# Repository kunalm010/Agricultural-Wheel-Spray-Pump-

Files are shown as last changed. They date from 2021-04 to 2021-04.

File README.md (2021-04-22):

# Agricultural-Wheel-Spray-Pump-
final assembly
Rear Shaft Sub Assembly
Front Shaft Sub Assembly
Crank_spray Frame sub Assembly
Frame Sub Assembly
Tank-Pump Sub Assembly

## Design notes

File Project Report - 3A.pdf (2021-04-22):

## Machine System Design

### A Project Report On

### “Agricultural Wheeled Spray Pump”

### Submitted by

### Group 3-A

### BT18MEC064 – KUNAL SONAWANE BT18MEC068 – SAURABH KHODE BT18MEC096 – BHAVIN YARDI

### Under the guidance of

### Prof. Dr. H.T.Thorat

### Department Of Mechanical Engineering

VNIT, Nagpur.

### 1. Name of Machine: Agricultural Wheeled Spray Pump

### 2. Purpose of the Machine: To spray pesticides on crops through

manual efforts.

This machine is a manually operated system and through this Machine we can reduce the maximum effort required for spraying Pesticides as well as we can spray pesticides in any direction or Around the crops at any height crops.

### 3. Design Objective: The conventional pesticide sprayers load the

farmer’s back with heavy storage tank which has to be carried all along the spraying process, which increases the efforts of the farmer. The objective of this machine is to fulfil the pesticide requirements of the farm at maximum rate, while reducing the efforts of the farmer.

### 4. Broad Design Specifications:

- Discharge – 3L/min
- No of nozzles – 3
- Area covered in one day – 6.4 Acre per day
- Spray per m2 – 82.873ml

### 5. Selection of Process and Mechanism:

Pressure Generation Process: Two types of pump can be used for the pressure generation process:

### 1. Centrifugal Pump: A centrifugal pump is a mechanical device

designed to move a fluid by means of the transfer of rotational energy from one or more driven rotors, called impellers.

The impeller is the key component of a centrifugal pump. It consists of a series of curved vanes. These are normally sandwiched between two discs (an enclosed impeller).

Fluid enters the impeller at its axis and exits along the circumference between the vanes. The impeller is connected through a drive shaft to a motor and rotated at high speed (typically 500-5000rpm). The rotational motion of the impeller accelerates the fluid out through the impeller vanes into the pump casing.

The action of the impeller increases the fluid’s velocity and pressure and also directs it towards the pump outlet.

There are two basic designs of pump casing: volute and diffuser. The purpose in both designs is to translate the fluid flow into a controlled discharge at pressure.

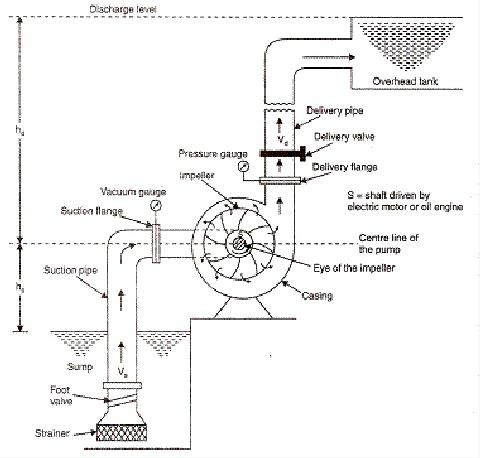
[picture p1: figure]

### 2. Reciprocating Pump: Reciprocating Pump is a Positive Displacement

type pump that works on the principle of movement of the piston in forwarding and backward directions.

It is a machine that converts mechanical energy into hydraulic energy. Reciprocating pumps are in use where a certain quantity of fluid has to be transported from the lowest region to the highest region by the application of pressure. The liquid is sucked keeping the delivery valve close and is pushed out while keeping the intake valve close creating a pressure at nozzle.

The rotatory motion of the wheel shall be used to drive the crank and convert the rotary motion into reciprocatory motion of the piston which will then cater to the process of pressure generation.

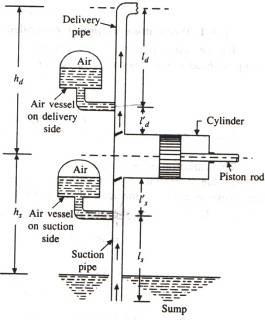
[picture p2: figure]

Pressure Generation is done by reciprocating pump.

- Advantages of reciprocating pump over centrifugal pump:
1. Reciprocating pump is used at a high-pressure head and Centrifugal Pumps are used at low or medium pressure head because the pressure generated in centrifugal pumps is limited due to the limitation on the speed of the shaft.
2. In reciprocating pumps low discharge is obtained which is a desired output for our case.

### 6. Design of Mechanism:

- Working of machine: The Reciprocating Pump has been used in the machine for pressure generation.

The slider crank Mechanism of the pump will be powered by the farmer himself. The total power requirement of the machine will depend on the discharge required as well as the height at which the pesticide is to be pumped. The discharge and the height of spray will vary from farm to farm and the calculations in this report have been done for the Wine-Yard farm. In addition, to the power required for spraying of pesticides the farmer will also need to exert some power to overcome the friction and facilitate the movement of the machine. Because there is a limit to the power which the farmer can exert, the discharge needs to be lowered by attaching the nozzles only one side of the frame. Chain Sprocket Mechanism has been used for power transmission. Freewheel has been attached on the crankshaft to avoid the power transmission in the reverse direction.

- Front Wheel Selection: A bigger wheel meant more stability to the cart but at the same time it would reduce the angular velocity of the front wheel, as the linear speed of the wheel would more or less remain constant. Lower angular velocity of the wheel would mean greater requirement of torque which would lead to the farmer exerting higher amount of force. Hence, we choose diameter of front wheel to be 30cm(smaller) and that of rear wheels to be 40cm(larger) thus ensuring stability and reducing overall torque requirement.
- Sprocket Wheel and Speed Ratio: In order to reduce the torque requirement, the angular velocity of the crankshaft needed to be increased. The lower limit on the size of the front wheel was fixed due to stability issues. Hence, the speed of the crankshaft had to be increased by choosing a suitable velocity ratio of the chain-sprocket mechanism. The velocity ratio had to be increase as much as possible. But the maximum velocity ratio attainable is 2:1.
- Freewheel: It is mounted on crankshaft connected with sprocket chain drive. It will be used in power transmission in forward direction. But for initial pressure built-up, instead of moving the cart and closing the nozzle’s opening, freewheel will be rotated

in reverse direction with the help of handle connected at the end of crankshaft, that will rotate the crankshaft and will setup initial pressure without moving the cart

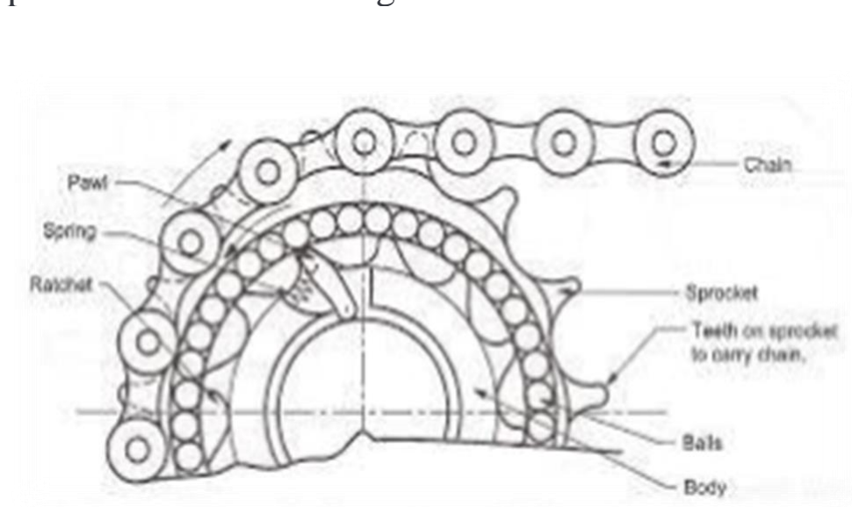
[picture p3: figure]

- DESIGN SELECTION: While using the reciprocating pump for the pressure generation process, the pump could be designed in two ways. One being with a fixed cylinder and the other with fixed piston. We analysed both the designs and finally decided to go with fixed cylinder reciprocating pump because of the following reasons:
1. Excessive length of linkages is required in the fixed piston type of reciprocating pump. Due to this, fixed piston type of reciprocating pump results in a less compact design.

2. As suction pipe will also reciprocate along with the cylinder in the fixed piston type of reciprocating pump, the design of suction pipe will create complication in design of actual pump.

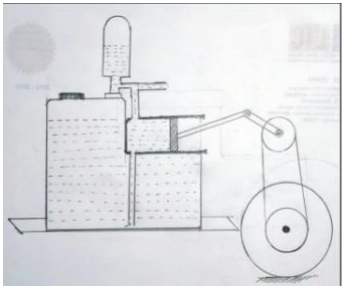
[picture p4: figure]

FIXED CYLINDER RECIPROCATING PUMP

FIXED PISTON RECIPROCATING PUMP

- Average Torque/Maximum Torque: The maximum angular velocity attainable on the machine is close to 90rpm which eliminates the use of flywheel in machine as flywheel works on higher rpm. Hence, the machine cannot be designed for average torque but has to be design for maximum torque required.

### 7. Power Transmission Chain:

### 8. Calculation of Power and Speed Requirement:

- Discharge = 3L/min
Assumed Cd = 0.5
Therefore, Design Discharge = 6L/min
- Number of Nozzles = 3
Therefore, Discharge per nozzle = 2L/min
- Speed of farmer = 0.7m/s
Radius of wheel = 0.15m
Angular speed of wheel = 4.67rad/s
Angular speed of crank = 9.34rad/s = 89.1267rpm Assumed Bore – stroke (d-l) ratio = 1:2

Calculation of bore diameter and stroke length,

FARMER | FRONT WHEEL
SPROCKET
PISTON | CRANK | FREEWHEEL

Since,

Bore diameter, d = 3.5cm
Stroke length, l = 7cm
- Calculation of Suction and Delivery pipe diameter,

Nozzle exit diameter = 2mm (Given Specification)

Therefore,

= 2L/min
Vexit = 10.6m/s (exit velocity at nozzle)

Nozzle inlet diameter = 6.35mm

Therefore,

= 2L/min

Vinlet = 1.05m/s (inlet velocity at nozzle)

Since, Velocity in suction pipe = velocity in delivery pipe = Vinlet = 1.05m/s

Therefore,

= 6L/min

Ds = 1.1cm

Therefore, diameter of suction pipe = diameter of delivery pipe = 1.1cm

- Calculation of suction and delivery head: Given Specifiaction:
Length of delivery pipe = 1m Length of suction pipe = 0.25m

Assuming the free surface of pesticides in tank as datum.

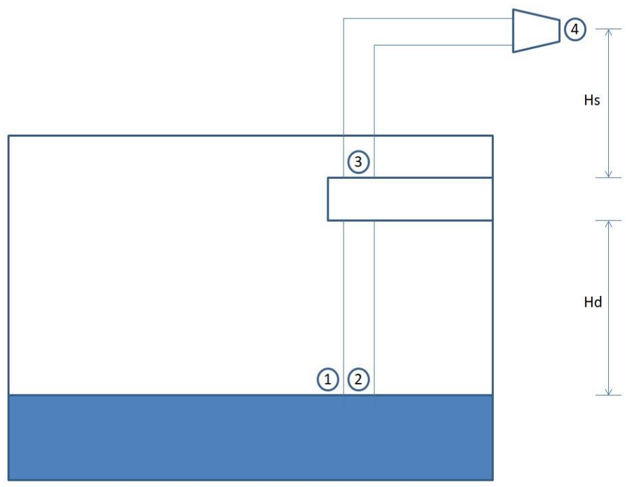
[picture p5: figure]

1. Suction head (Hs) =
+

Applying Bernoulli’s Principle on 1 and 2,

+ =

+

+

+ 0 =

+

+ h2

Therefore, Hs =
= 10.3m
2. Delivery head (Hd) =
+

Applying Bernoulli’s Principle on 3 and 4,

+ =

+

+

=

+ -

Therefore, Hd =
+ = 17.28
- Calculation of acceleration head Ha:

Ha =

Has =

= 0.008425cos ( )

Had =

= 0.337cos ( )

- Force required for generating head: During suction,

Fs =

( | )

=

( | ( | ))
Fs = 97.21 + 0.795cos ( | )

Fd =

( | )

= -

( | ( | ))

Fd = -(163.09 + 3.18cos ( ))

- Torque required for generating load:

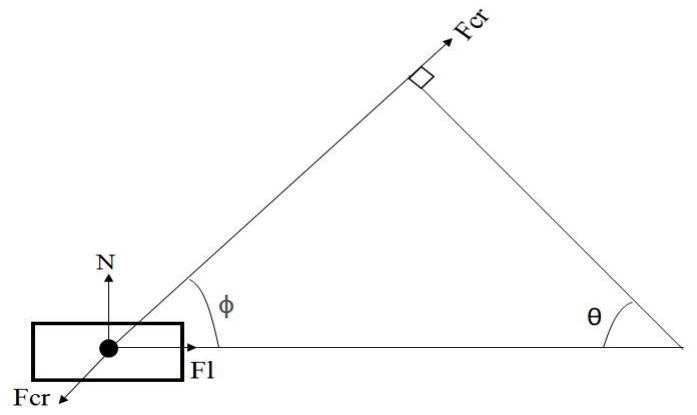
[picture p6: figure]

During suction,

Ts =

( | ) *
( | ) √ (
( | ))
+
√ (
| | | ( | ))
Ts = ( | ( | )) | ( | ) * | ( | ) √ ( | ( | ))
+
√ ( | ( | ))

During delivery,

Td =

( | ) *
( | ) √ (
( | ))
+
√ (
( ))

Td = -

( | ( | )) | ( | ) * | ( | ) √ ( | ( | ))
+
√ ( | ( | ))

- Plotting T VS diagram during delivery as well as suction.

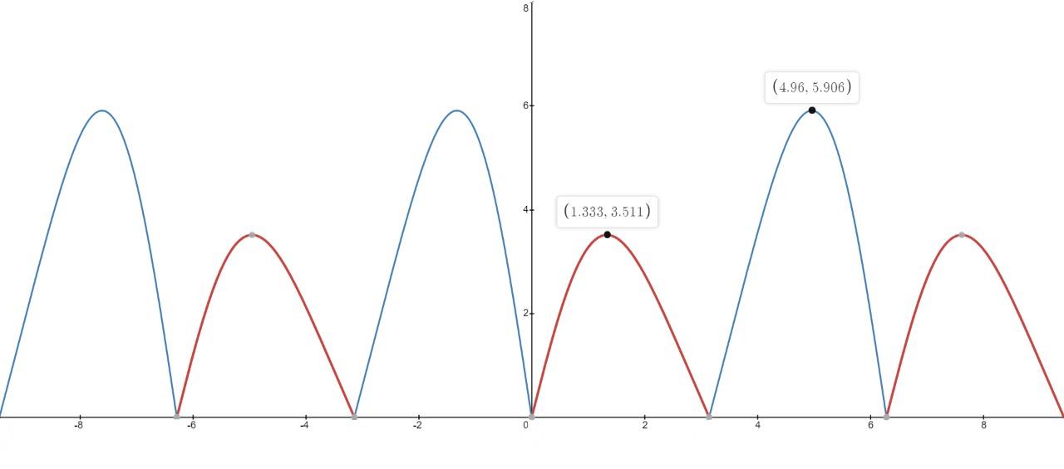
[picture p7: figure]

We obtain,

Maximum torque required during the cycle = 6Nm

- Therefore, maximum power required = Tmax*w = 56Watts
- Considering following losses:
1) Friction loss in suction pipe
2) Friction loss in delivery pipe

3) Losses in reciprocating pump

Assuming these losses to be 10%
Taking efficiency of chain sprocket mechanism = 98% Power drawn by machine for pressure generation =

= 77.8Watts
Weight of the machine = 60kg
Coefficient of friction between tyre and soil = 0.1
Linear velocity of machine = 0.7m/s

Therefore, total power required to overcome friction -= 60*9.881*0.1*0.7
= 41.2Watts

Therefore, Total power requirement of the machine = 77.8 + 41.2 = 119Watts

### 9. Force Analysis:

- Weight Distribution on Front and Rear Shaft:

Given Specifications:

- Wheelbase = 840mm
- Let force on Rear shaft be Fr and force on front shaft be Ff

Calculations of forces on front and rear shaft:

Fr + Ff = (40+15) *9.81
= 539.55N

Taking moment about A = 0,

-40(9.81) *225 – 15(9.81) *540 + Ff (840) = 0

Therefore, Ff = 199.70N
Fr = 339.84N

- Force analysis of Rear Shaft:

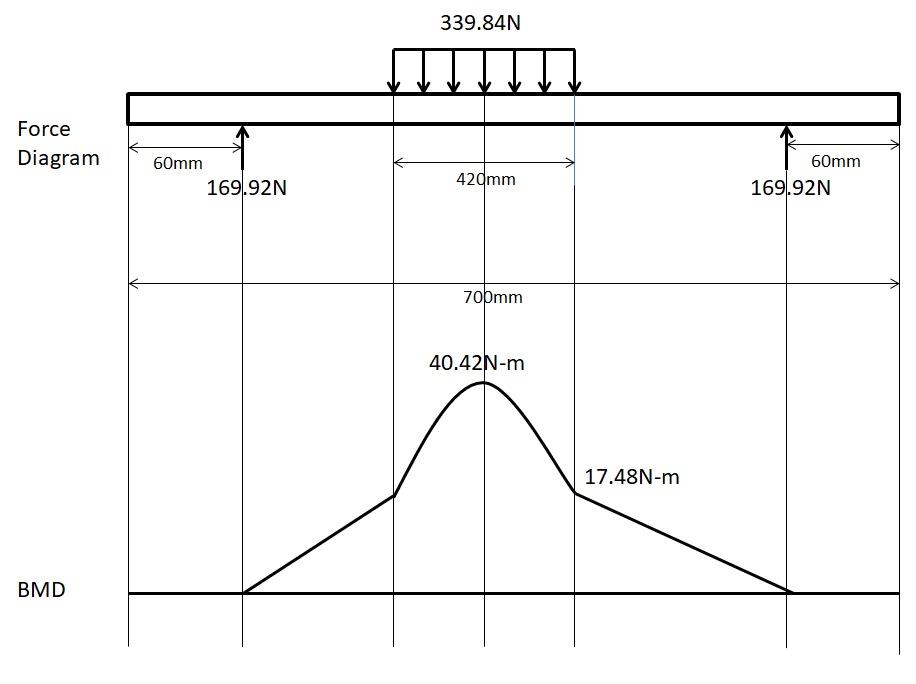
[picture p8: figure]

Total Weight acting on rear shaft in downward direction = 339.84N Therefore, Upward forces on bearings at A and B = 339.84/2 =169.92N

- Force Analysis of Front Shaft:

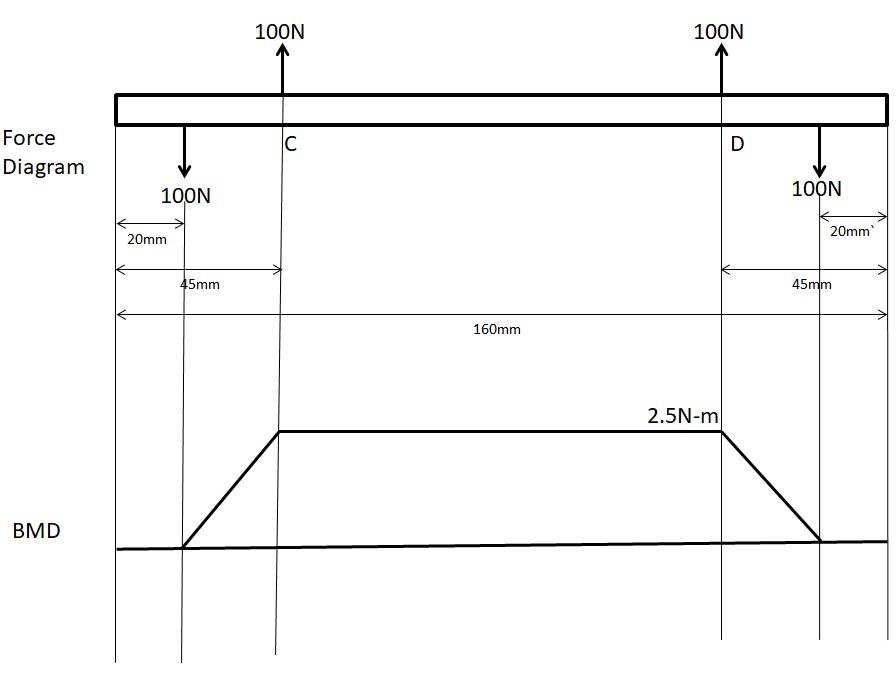
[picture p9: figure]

Total Weight acting on front shaft in downward direction = 200N Therefore, Upward forces on bearings at C and D = 200/2 =100N

- Force Analysis of Crank-Shaft:

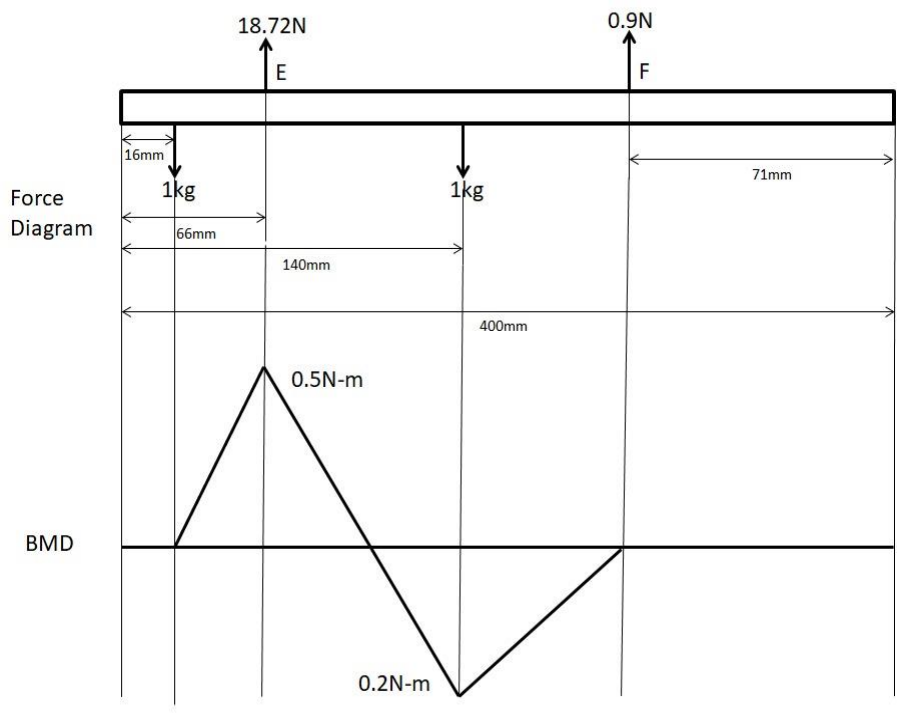
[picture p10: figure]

Total Weight acting on crank shaft in downward direction = 19.62N

Upward forces acting on shaft due to bearing at E and F,

Fe + Ff = 19.62N
Taking moment about E = 0,

1*9.81 * 50 – 1*9.81 * 74 + Ff*263 = 0

Therefore, Ff = 0.9N
Fe = 18.72N

- Force Analysis of Crank pin:

Force acting on point G = 2*9.81 = 19.62N Moment about point G = 19.62*(51-17.5) = 0.65727N-m

- Force Analysis of Angle bar:

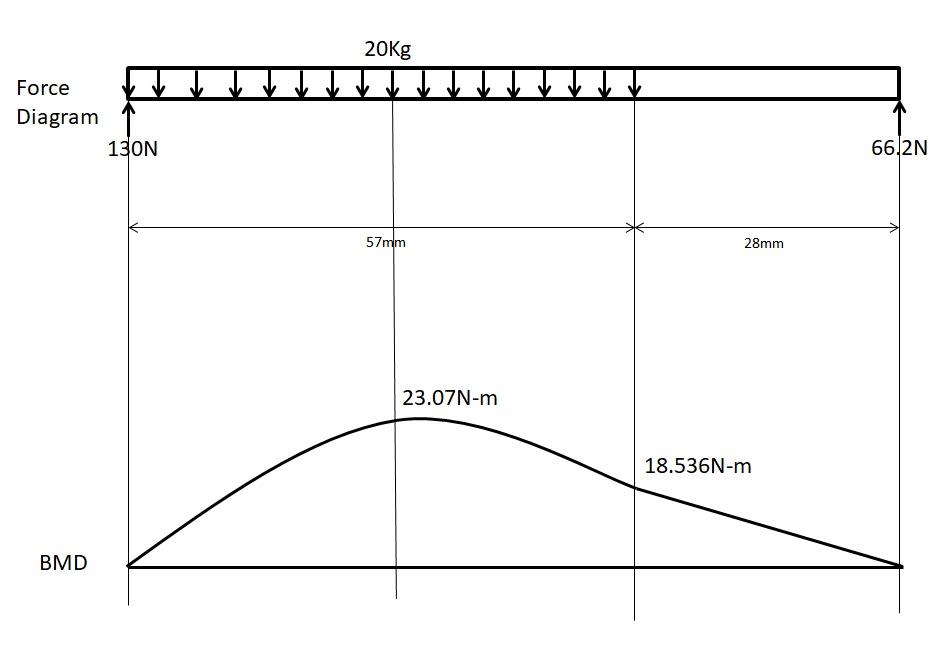
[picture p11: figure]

Total downward force acting on angle bar = 196.2N Fa + Fb = 196.2N

Taking moment about point A = 0
-196.2 * 28.5 + Fb * 85 = 0 Fb = 66.2N
Fa = 130N

- Force Analysis of Vertical Handle Support

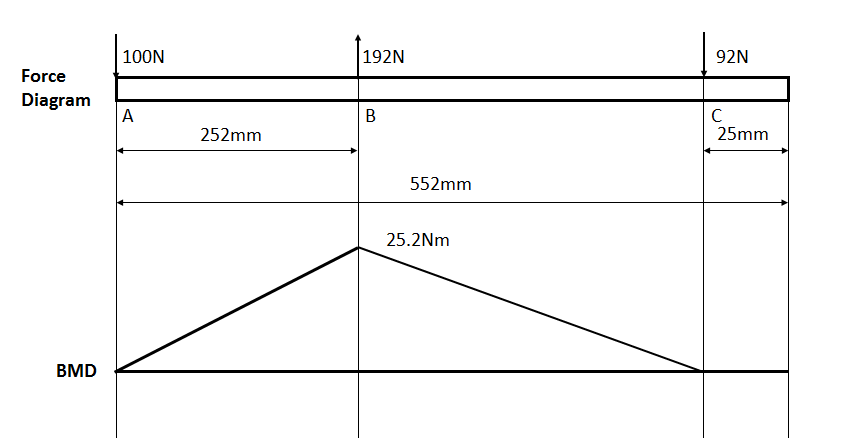
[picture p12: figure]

Total Lateral Force = 92N
Fa + Fb = 92

Taking Moment @A = 0
92*527 = Fb*300

Fb = 192N
Fa = 100N

- Force to be exerted by Farmer:
1. For Pressure Generation:

Given Specifications:

Power required = 76Watts
Height of application of force = 0.5m Torque requirement on crankshaft = 8.2N-m
Torque applied on Front Shaft = 16.4N-m

Therefore, force to be applied by the Farmer = 16.4/0.5 = 32.8N

2. For Overcoming Friction:

Given Specifications:

Weight of the machine = 60kg
Coefficient of friction between tyre and soil = 0.1

Therefore, force to be applied by the Farmer = 60*9.81*0.1 = 58.86N

Total force required to be exerted by the Farmer = 32.8 + 58.86 = 91.66N

10.Design of Machine Elements

- Calculation for Diameter of Rear Shaft: Given Specification,
Maximum Moment Mb = 31.43Nm
Material Selected – Structural Steel (Syt = 250MPa) Factor of safety (fs) = 1.5

Since,

Tmax =

= 83.33MPa

Also, Tmax =

Therefore, d = 12.14mm = 20mm(standard)

Diameter of Rear Shaft = 20mm

- Calculation for Diameter of Front Shaft:

Diameter of Front Shaft:
Given Specification,
Maximum Moment Mb = 2.5Nm
Material Selected – Structural Steel (Syt = 250MPa) Factor of safety (fs) = 1.5

Since,

Tmax =

= 83.33MPa

Also, Tmax =

Therefore, d = 5.34mm= 10mm(standard)

Diameter of Front Shaft = 10mm

- Calculation for Diameter of Crank Shaft:

Given Specification,
Maximum Moment Mb = 0.5Nm
Material Selected – Structural Steel (Syt = 250MPa) Factor of safety (fs) = 1.5
Power Requirement Pr = 76Watts
Crank Speed N = 90rpm
Load Factor Ki = 1.75

Since,

Tmax =

= 83.33MPa

Torque due to Power Transmission Td =

Therefore, Td = 14.11Nm

Also, Tmax = √

Therefore, d = 9.5mm= 10mm(standard)

Diameter of Crank Shaft = 10mm

- Calculation for diameter of Crank Pin:

Given Specification,
Maximum Moment Mb = 0.65727Nm
Material Selected – Structural Steel (Syt = 250MPa) Factor of safety (fs) = 1.5
Power Requirement Pr = 76Watts
Crank Speed N = 90rpm
Load Factor Ki = 1.75

Since,

Tmax =

= 83.33MPa

Torque due to Power Transmission Td =

Therefore, Td = 14.11Nm

Also, Tmax = √

Therefore, d = 9.52 = 10mm(standard)

Diameter of Crank Pin = 10mm

- Calculation Of thickness of angle bar(t):

Given Specification,
Maximum Moment Mb = 23.07Nm
Material Selected = Structural Steel (Syt = 250MPa) Factor of safety (fs) = 1.5
Length of angle bar (l) = 85cm

Maximum permissible stress(σ) =

( | )
( | )
=

=

166.667 =
Therefore, t = 0.988mm = 1mm
- Calculation of thickness of Support:

Given Specifications:
Maximum Moment = 25.2N-m
Material Selected = Structural Steel (Syt = 250Mpa) Factor of safety (fs) = 1.5
Width of Bar (w) = 3cm

Maximum permissible stress(σ) =

( | )
( | )
=

=

166.667 =

Therefore, t = 5.4mm = 6mm

- Selection of Screw of Hub & Sprocket

Given Specifications:

Power Transmitted = 77.2Watts
Radius of Application of force = 31mm
Angular Velocity = 4.67rad/s
Material Selected = Hardened Steel (τmax = 350Mpa)

Torque Transmitted =
= 16.65N-m

Shear Force exerted on Bolt = = 537.1N
Shear Stress =

=

Diameter of Bolt = 1.7mm
Specification of screw = M2
- Bearings Selection
a. Rear Shaft

Radial Force on Bearing = 169.92N

So, according to Radial Force applied & Static Capacity

Bearing Series = 60
Bearing Specification = 6004
b. Front Shaft

Radial Force on Bearing = 100N

So, according to Radial Force applied & Static Capacity

Bearing Series = 60
Bearing Specification = 6000
c. Crank Shaft

Radial Force on Bearing = 18.72N

So, according to Radial Force applied & Static Capacity

Bearing Series = 60
Bearing Specification = 6000
- Sprocket and Freewheel Design:

Given Specifications:

Power transmitted = 77.8Watts Speed of crankshaft = 90rpm Speed of front-wheel shaft = 45rpm

Therefore, according to power transmitted and speed,

Pitch of sprocket (P) = 9.525mm

According to pitch,
Chain selected = R957
Weight/unit meter (w) = 4.1kg Breaking load (Fmax) = 8.9KN

Desired transmission ratio = 2
Therefore, Teeth on Freewheel (T1) = 26 Teeth on sprocket (T2) = 52

Pitch Diameter of Freewheel (Dp1) =
(

)

= 82mm

Pitch Diameter of Sprocket (Dp2) =
(

)

= 164mm

Pitch velocity (Vp) =

= 0.386m/s

Minimum value of factor of safety (FSmin) = 7.6

Checking for actual factor of safety:

1. Tangential force due to power transmission (Ft) =

= 201.554N

2. Centrifugal tension (Fc) =

= 0.0622N

3. Tension due to sagging of chain (Fs) = k*w*a

Coefficient for sag (k) = 4

Centre distance (a) = 40P = 0.381m

Therefore, Tension due to sagging of chain (Fs) = 6.2N

Service factor (k0) = k1* k2*k3*k4*k5*k6

Load factor (k1) = 1.25
Factor for distance regulation (k2) = 1.25 Factor for centre distance of sprocket (k3) = 1 Factor for the position of the sprocket (k4) = 1 Lubrication factor (k5) = 1
Rating factor (k6) = 1

Therefore, Total force on sprocket (F) = (Ft + Fc + Fs) *k0

= 324.77N

Factor of safety (FS) =

= 27.5

Therefore, FS > FSmin

Therefore, Sprocket is SAFE

Bearing area (A) = 0.28

Load on pin (f) = Ft * k0

= 315N

Therefore, Bearing pressure = 11.25N/

Allowable Bearing pressure = 30 N/

Therefore, Chain is SAFE

### 11. Part List

S.No | Component Name | Component Number | Material | Quantity | Drawing Number/Specifications
1 | Shaft | WSP 0101 | Structural Steel | 1 | 1
2 | Bearings | WSP 0102 | - | 4 | Series 6004
3 | Hub | WSP 0103 | Mild Steel | 2 | 2
4 | Locknut | WSP 0104 | - | 2 | M20x1
5 | Rim Pipes | WSP 0105 | Steel | 16 | 3
6 | Rim | WSP 0106 | Steel | 2 | -
7 | Tyre | WSP 0107 | Hard Rubber | 2 | Φ40mm
8 | Shaft | WSP 0201 | Structural Steel | 1 | 4
9 | Bearings | WSP 0202 | - | 2 | Series 6000
10 | Hub | WSP 0203 | Mild Steel | 1 | 5
11 | Locknut | WSP 0204 | - | 2 | M10x0.75
12 | Sprocket | WSP 0205 | Low Carbon steel | 1 | 6
13 | Screw | WSP 0206 | - | 2 | M2
14 | Rim Pipe | WSP 0207 | Steel | 6 | 7
15 | Rim | WSP 0208 | Steel | 1 | -
16 | Tyre | WSP 0209 | Hard Rubber | 1 | Φ30mm
17 | Vertical Support Bar | WSP 0301 | Structural Steel | 2 | 8
18 | Shaft | WSP 0302 | Structural Steel | 1 | 9
20 | Housing | WSP 0304 | Cast Steel | 2 | -
21 | Shaft Collar | WSP 0305 | Stainless Steel | 2 | 1C-043-S

22 | Bolt | WSP 0306 | - | 4 | M3
23 | Nut | WSP 0307 | - | 4 | M3
24 | Parallel Key | WSP 0308 | Stainless Steel | 1 | Φ16mm
25 | Taper Key | WSP 0309 | Stainless Steel | 1 | Φ10mm
26 | Crank Disc | WSP 0310 | Structural Steel | 1 | 10
27 | Crank Pin | WSP 0311 | Structural Steel | 1 | 11
28 | Journal Bearing | WSP 0312 | - | 1 | 7 SF 12-SS
29 | Freewheel | WSP 0313 | Low Carbon steel | 1 | 12
30 | Elbow Joint | WSP 0314 | PVC | 1 | NPS ½”
31 | Double-Y Joint | WSP 0315 | PVC | 1 | OD ¼”
32 | PVC Pipe | WSP 0316 | PVC | 4 | -
33 | Nozzle | WSP 0317 | Brass | 3 | Full conical
34 | Handle | WSP 0318 | Structural Steel | 1 | 13
36 | Roller Chain | WSP 0319 | - | 1 | R957
37 | Angle Bar | WSP 0401 | Structural Steel | 4 | 14
38 | Tank Supporting Plate | WSP 0402 | Structural Steel | 1 | 420x50x1mm
39 | Inclined Side Supports | WSP 0403 | Structural Steel | 2 | 53x20x1mm
40 | Vertical Handle Support | WSP 0404 | Structural Steel | 2 | 15
41 | Pushing Handle | WSP 0405 | Structural Steel | 1 | 16
43 | Angled Connecting Bar | WSP 0408 | Structural Steel | 2 | 19

44 | Shaft Supporting Block | WSP 0409 | Aluminium | 2 | 20
45 | Nut | WSP 0410 | - | 7 | M5
46 | Bolt | WSP 0411 | - | 7 | M5
47 | Tank | WSP 0501 | Plastic | 1 | 21
48 | Cylinder | WSP 0502 | Structural Steel | 1 | -
49 | Piston | WSP 0503 | Structural Steel | 1 | Φ3.5cm
50 | Connecting Rod | WSP 0504 | Structural Steel | 1 | 28
51 | Double-Threaded Cap | WSP 0505 | Plastic | 1 | 22
52 | One-way Valve | WSP 0506 | Plastic | 2 | -
53 | Flexible Pipe | WSP 0507 | PVC | 2 | Φ15mm

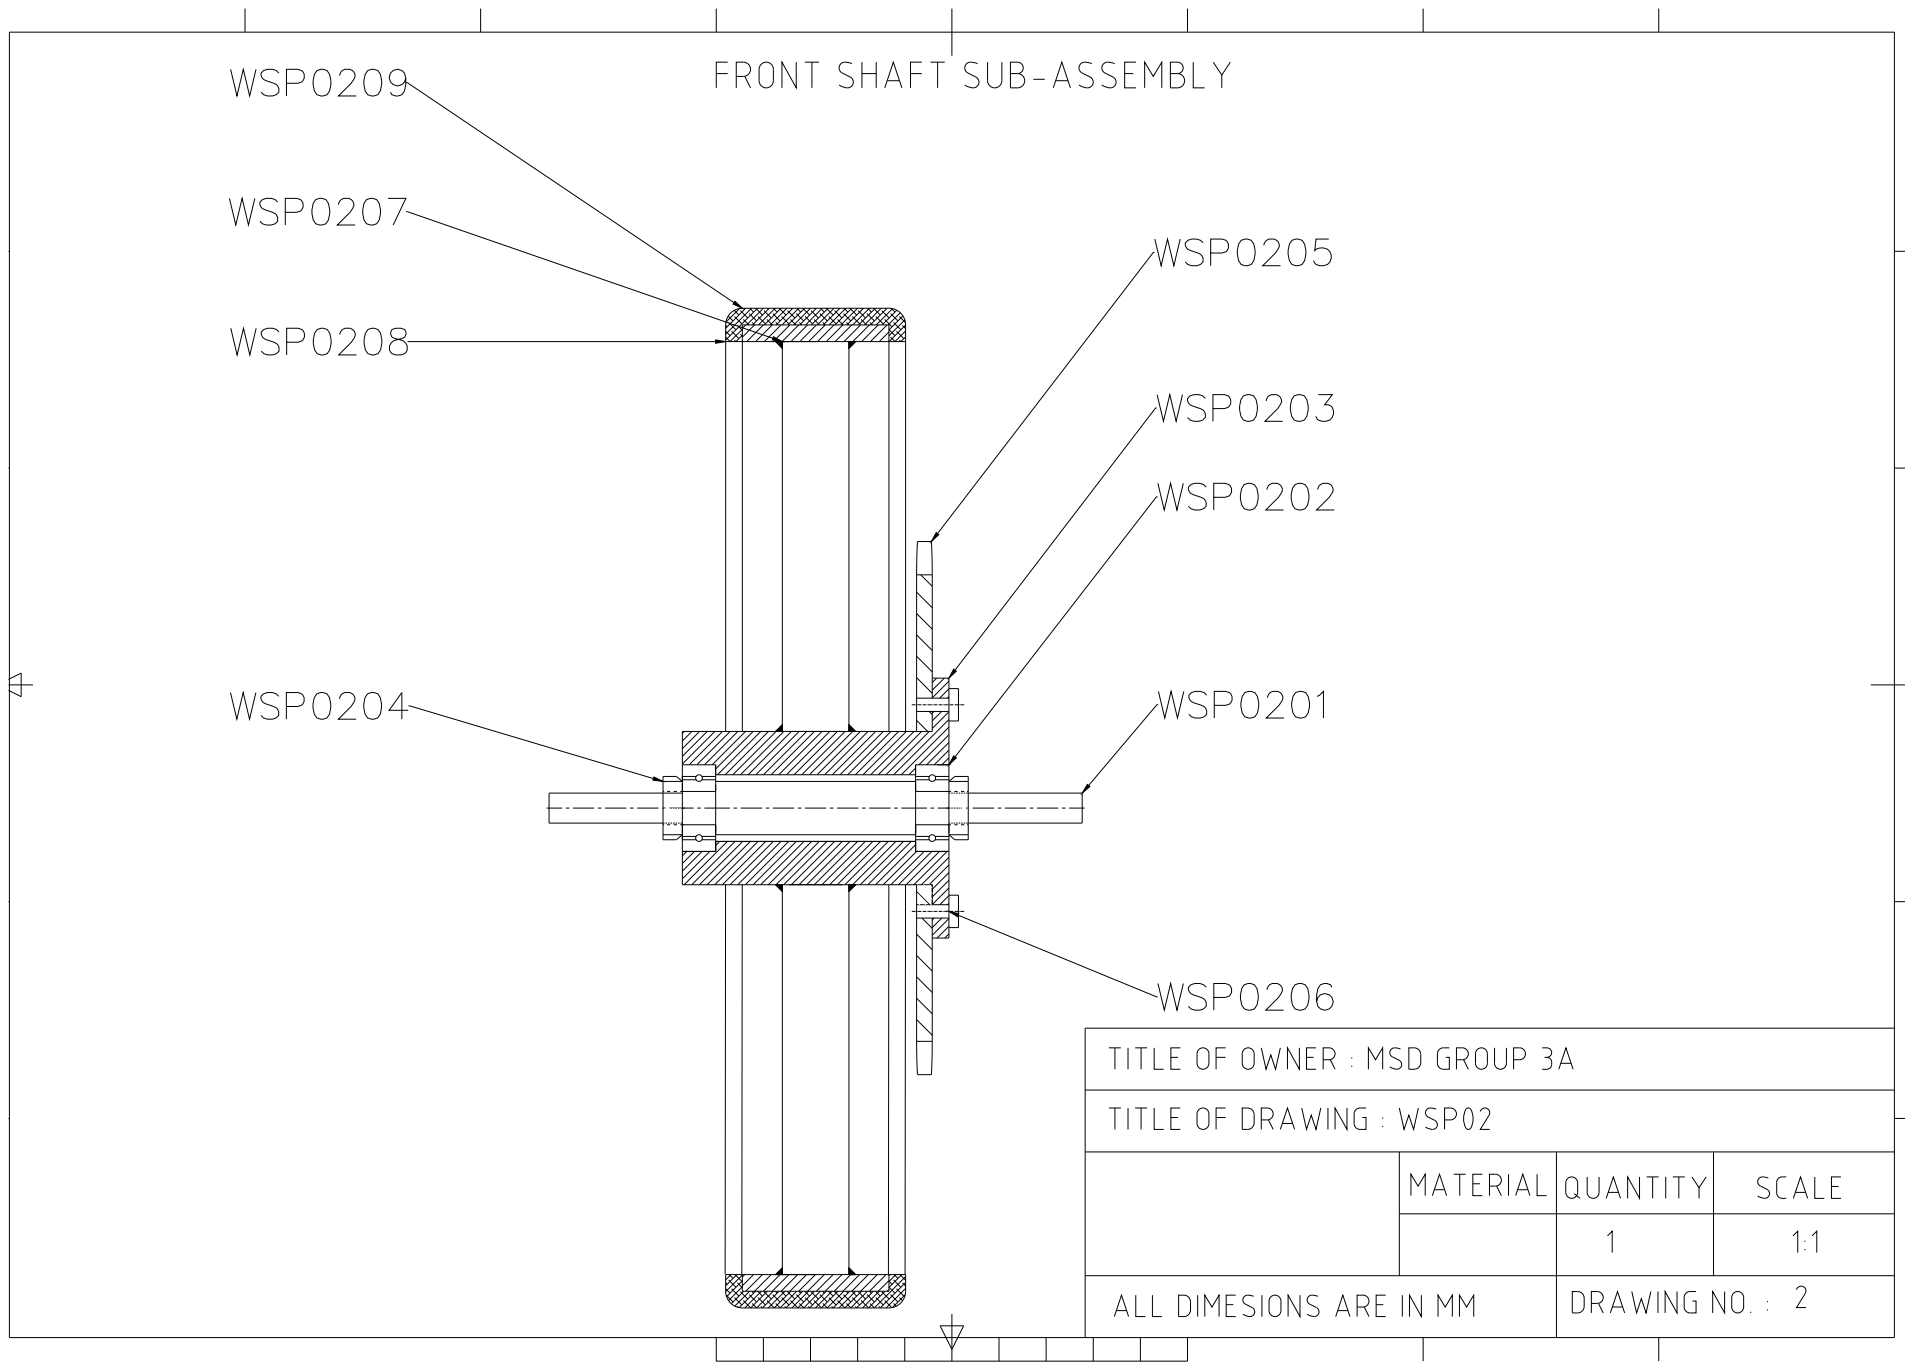
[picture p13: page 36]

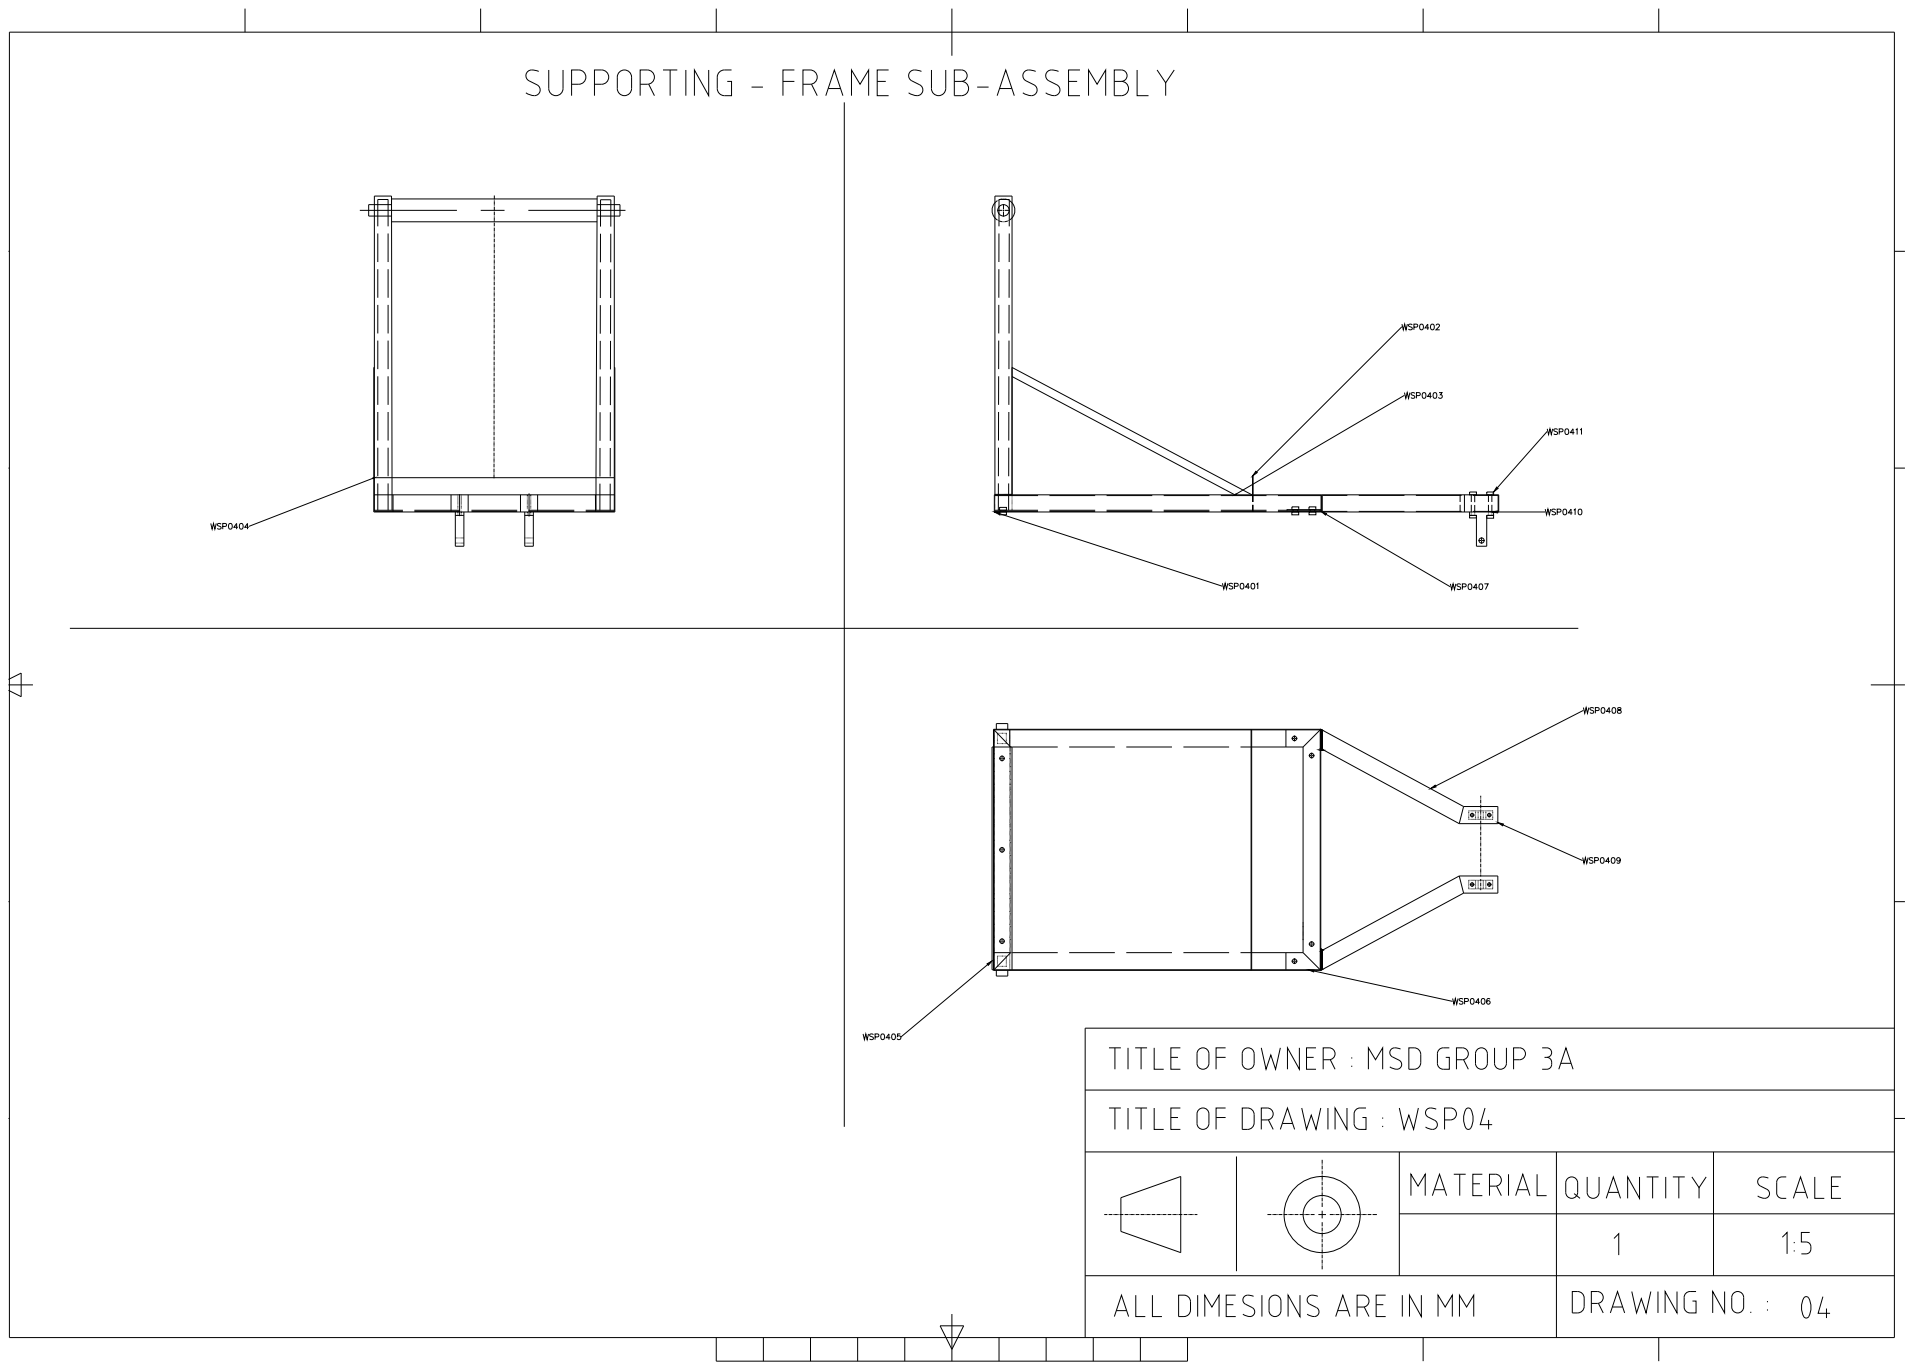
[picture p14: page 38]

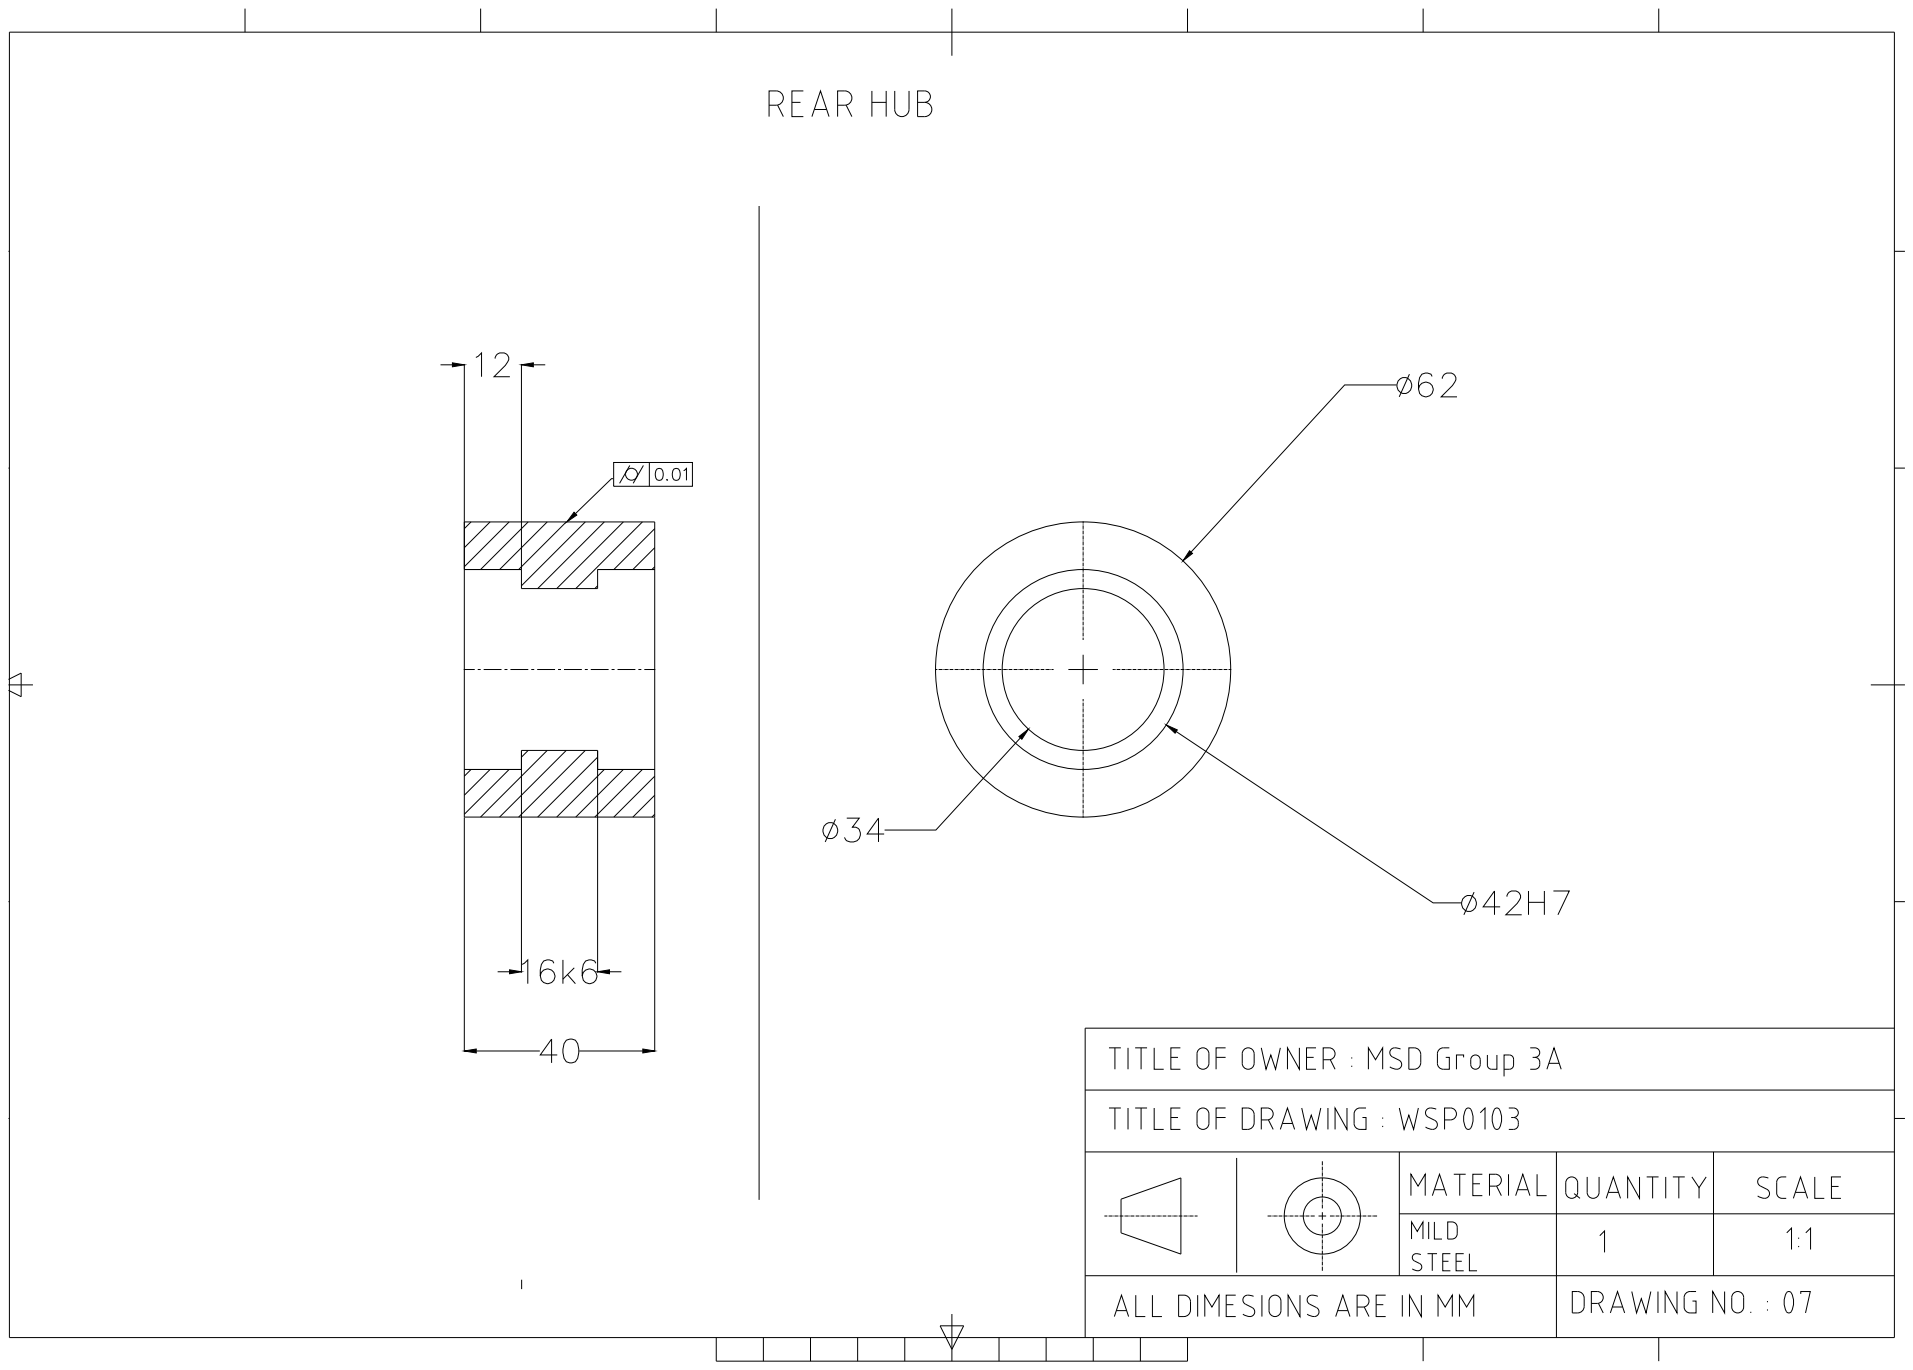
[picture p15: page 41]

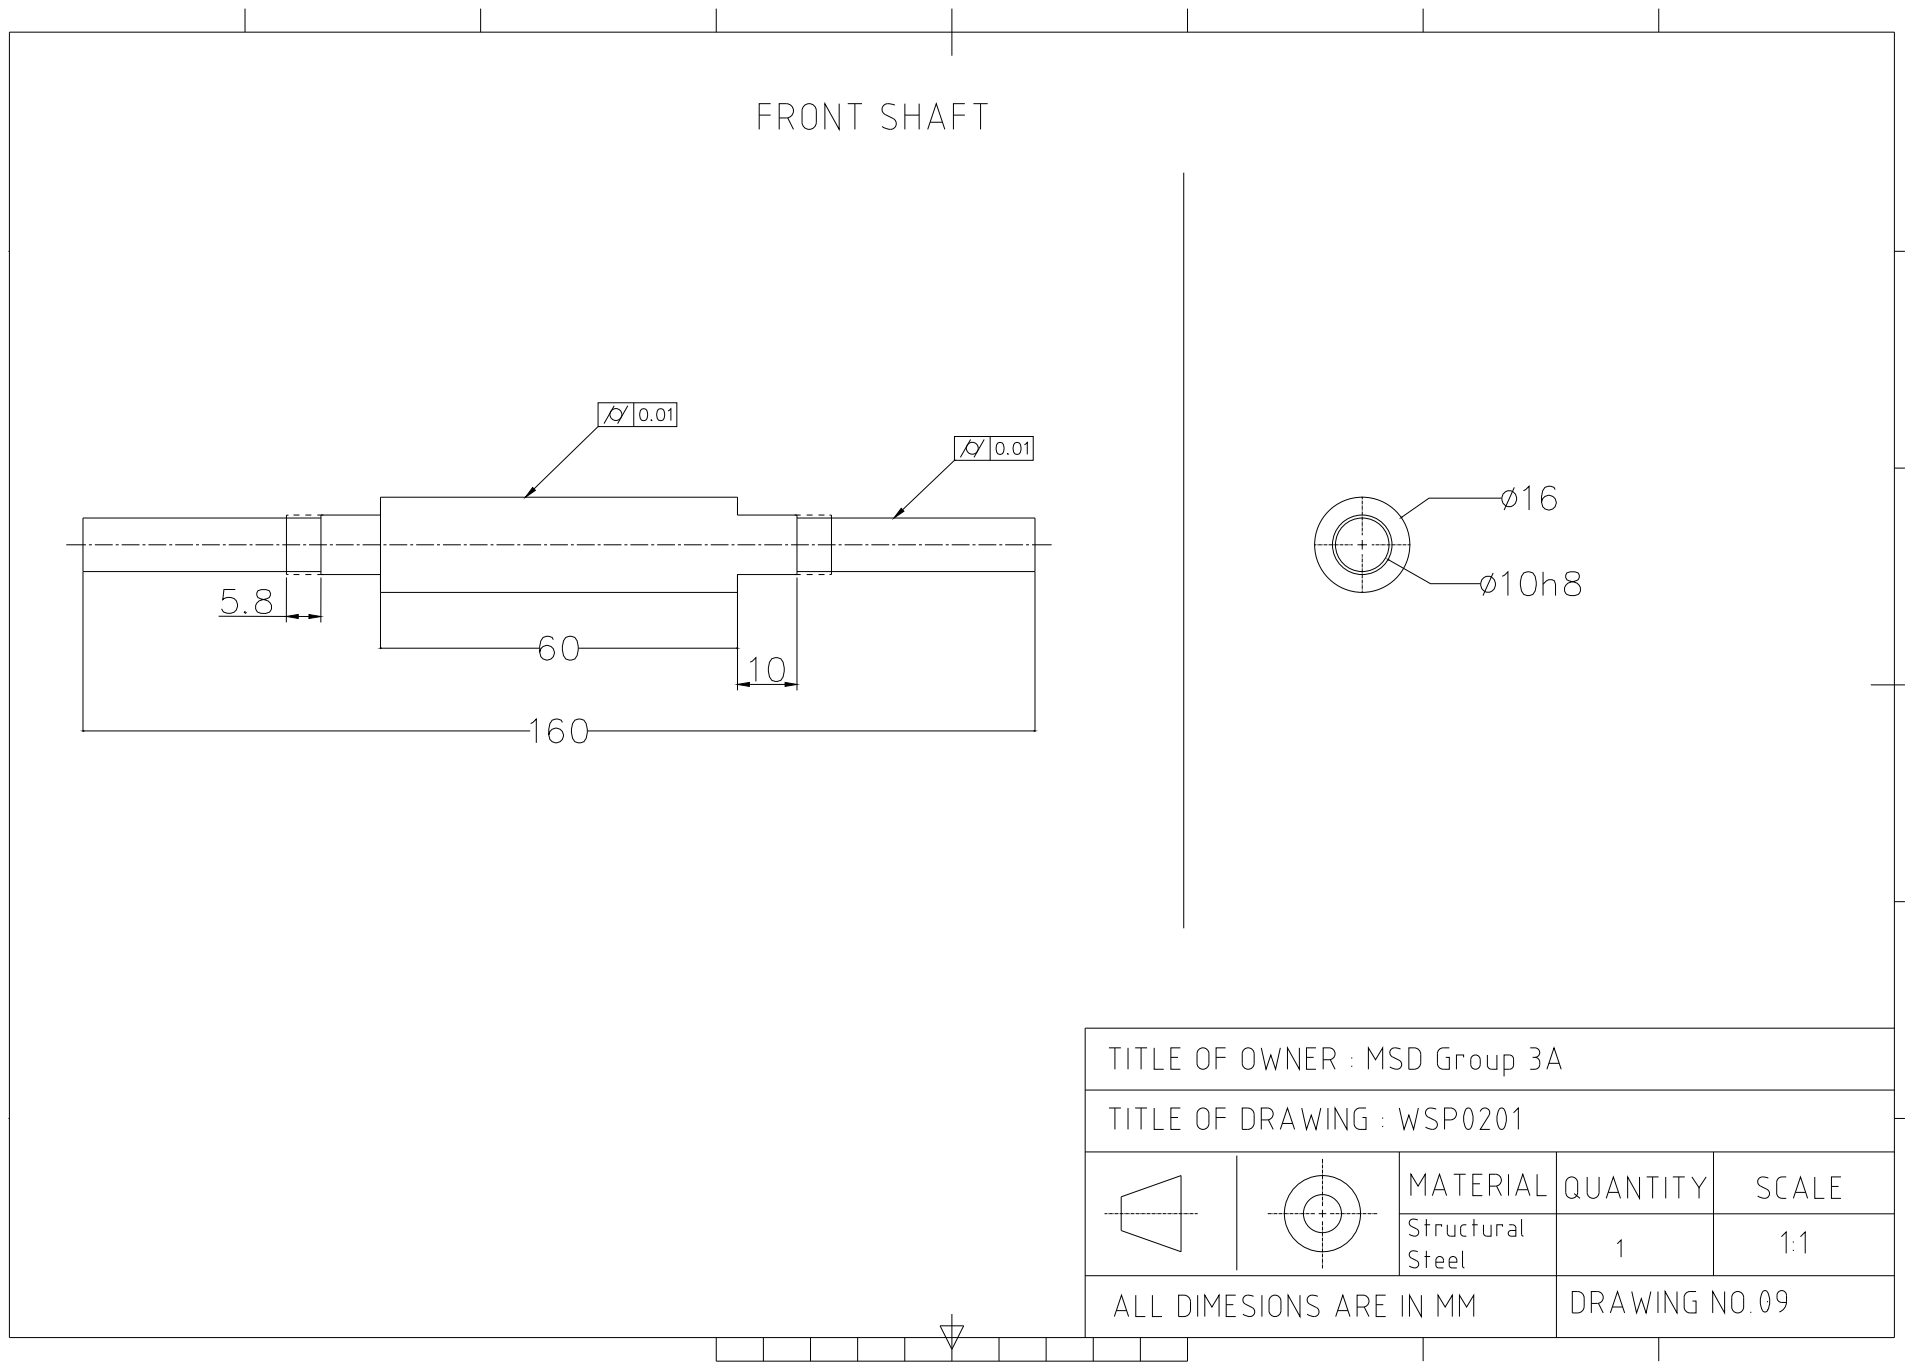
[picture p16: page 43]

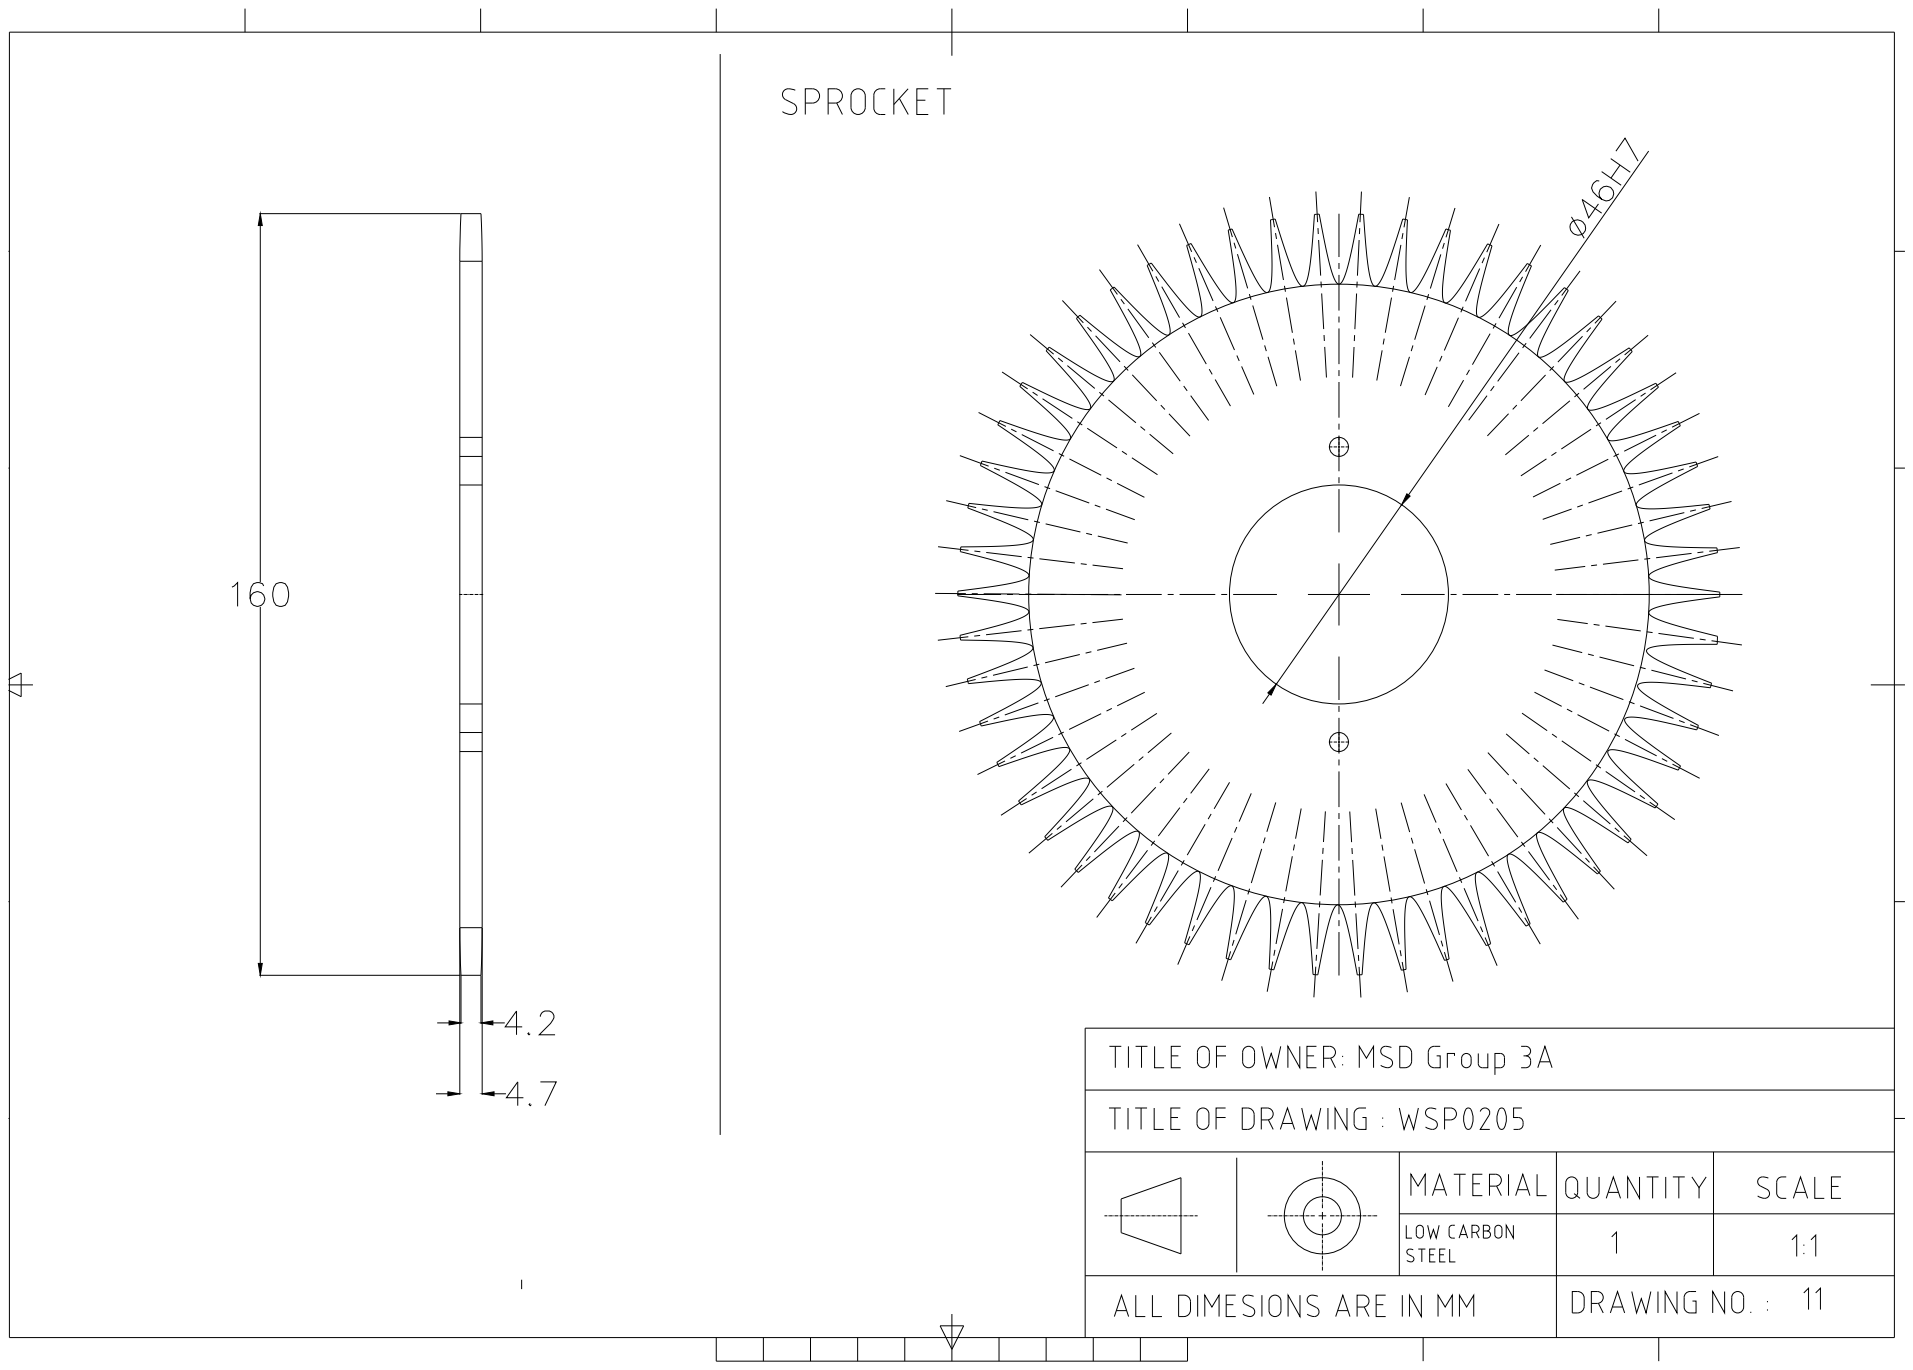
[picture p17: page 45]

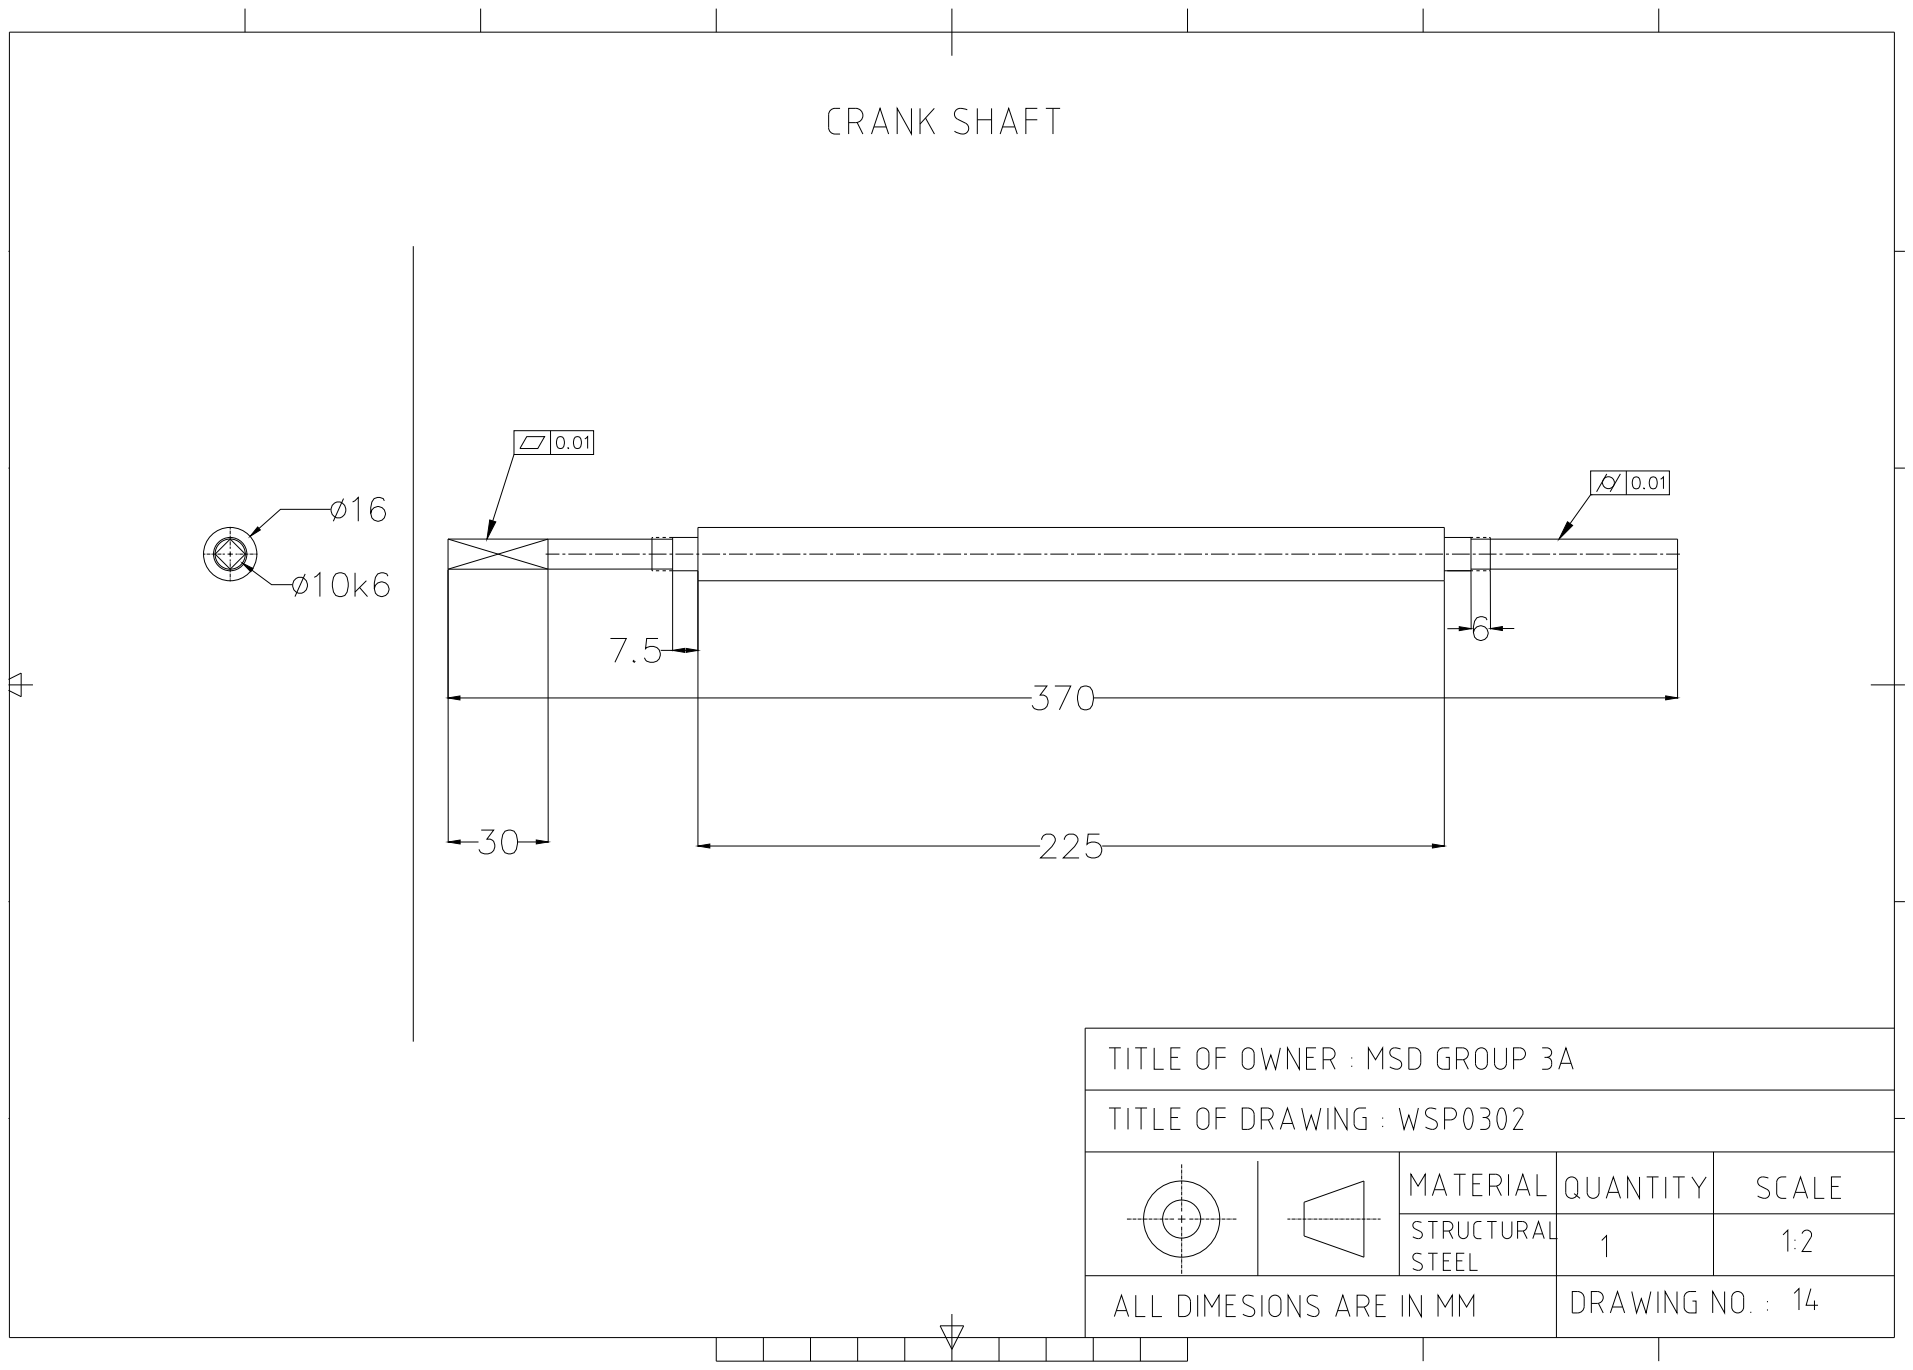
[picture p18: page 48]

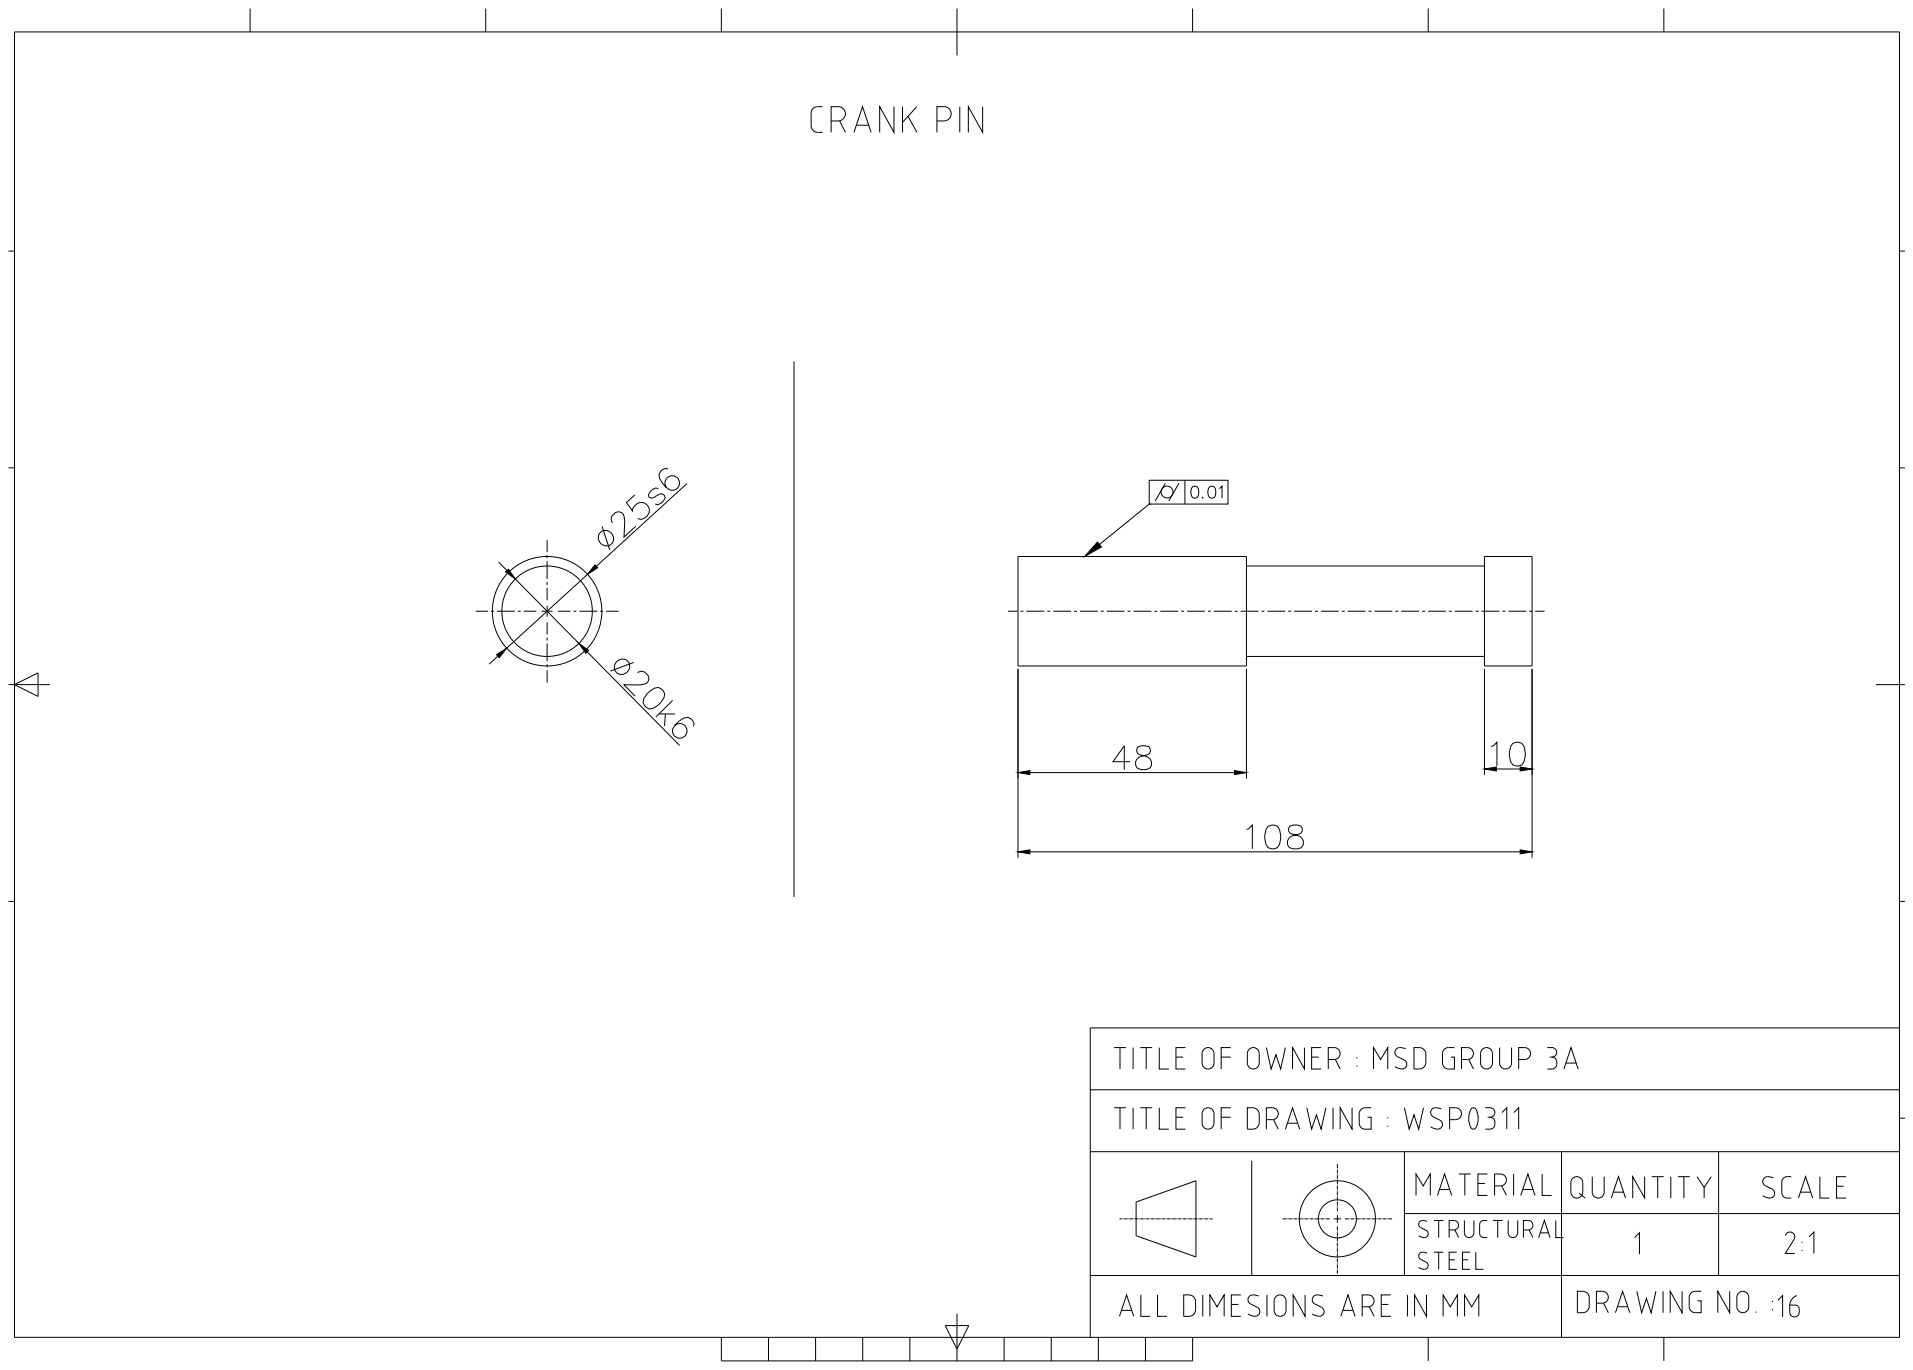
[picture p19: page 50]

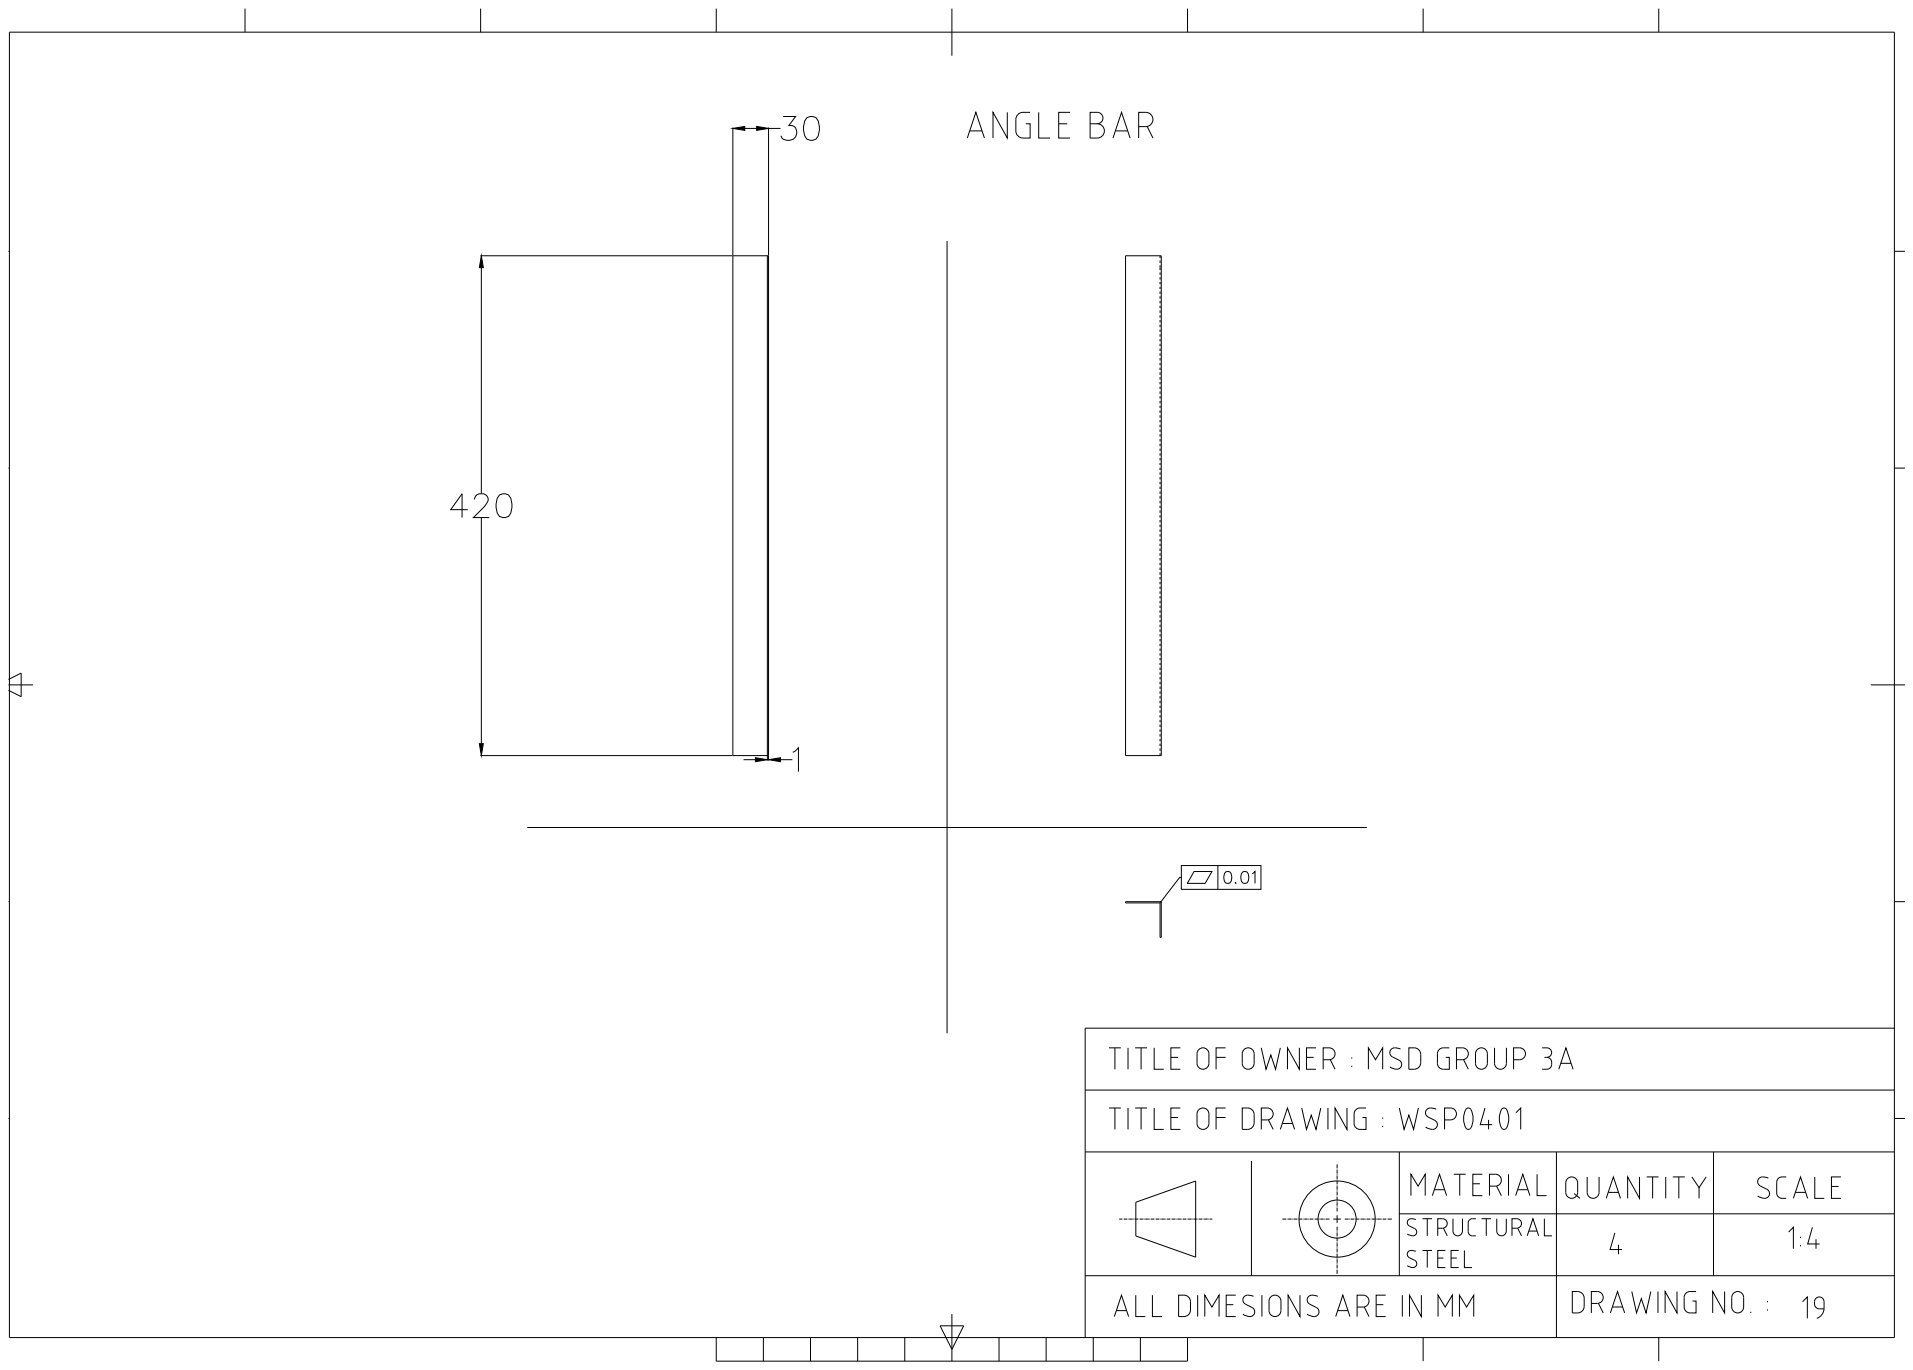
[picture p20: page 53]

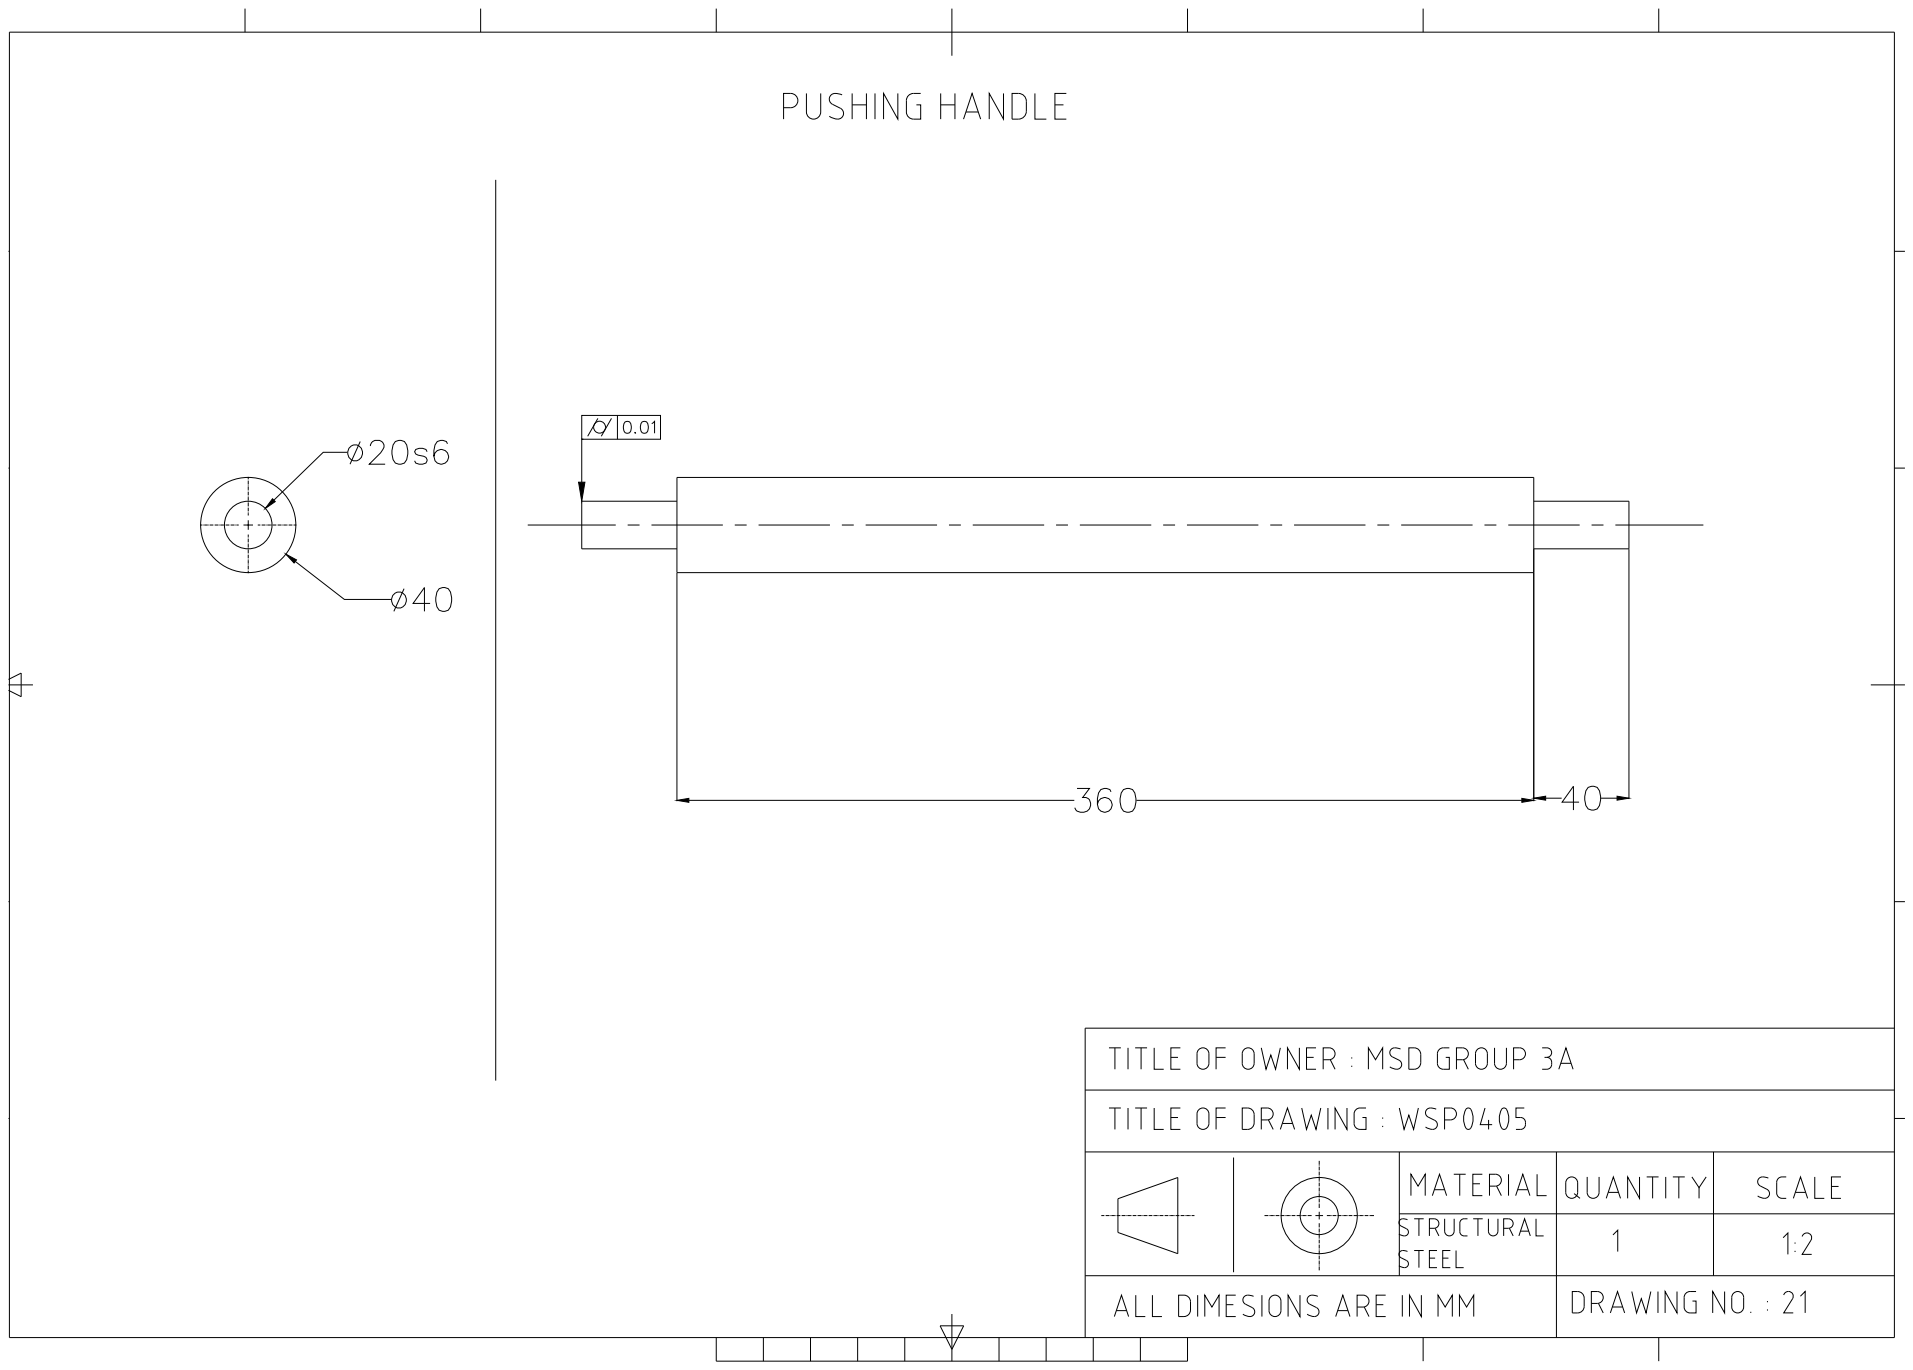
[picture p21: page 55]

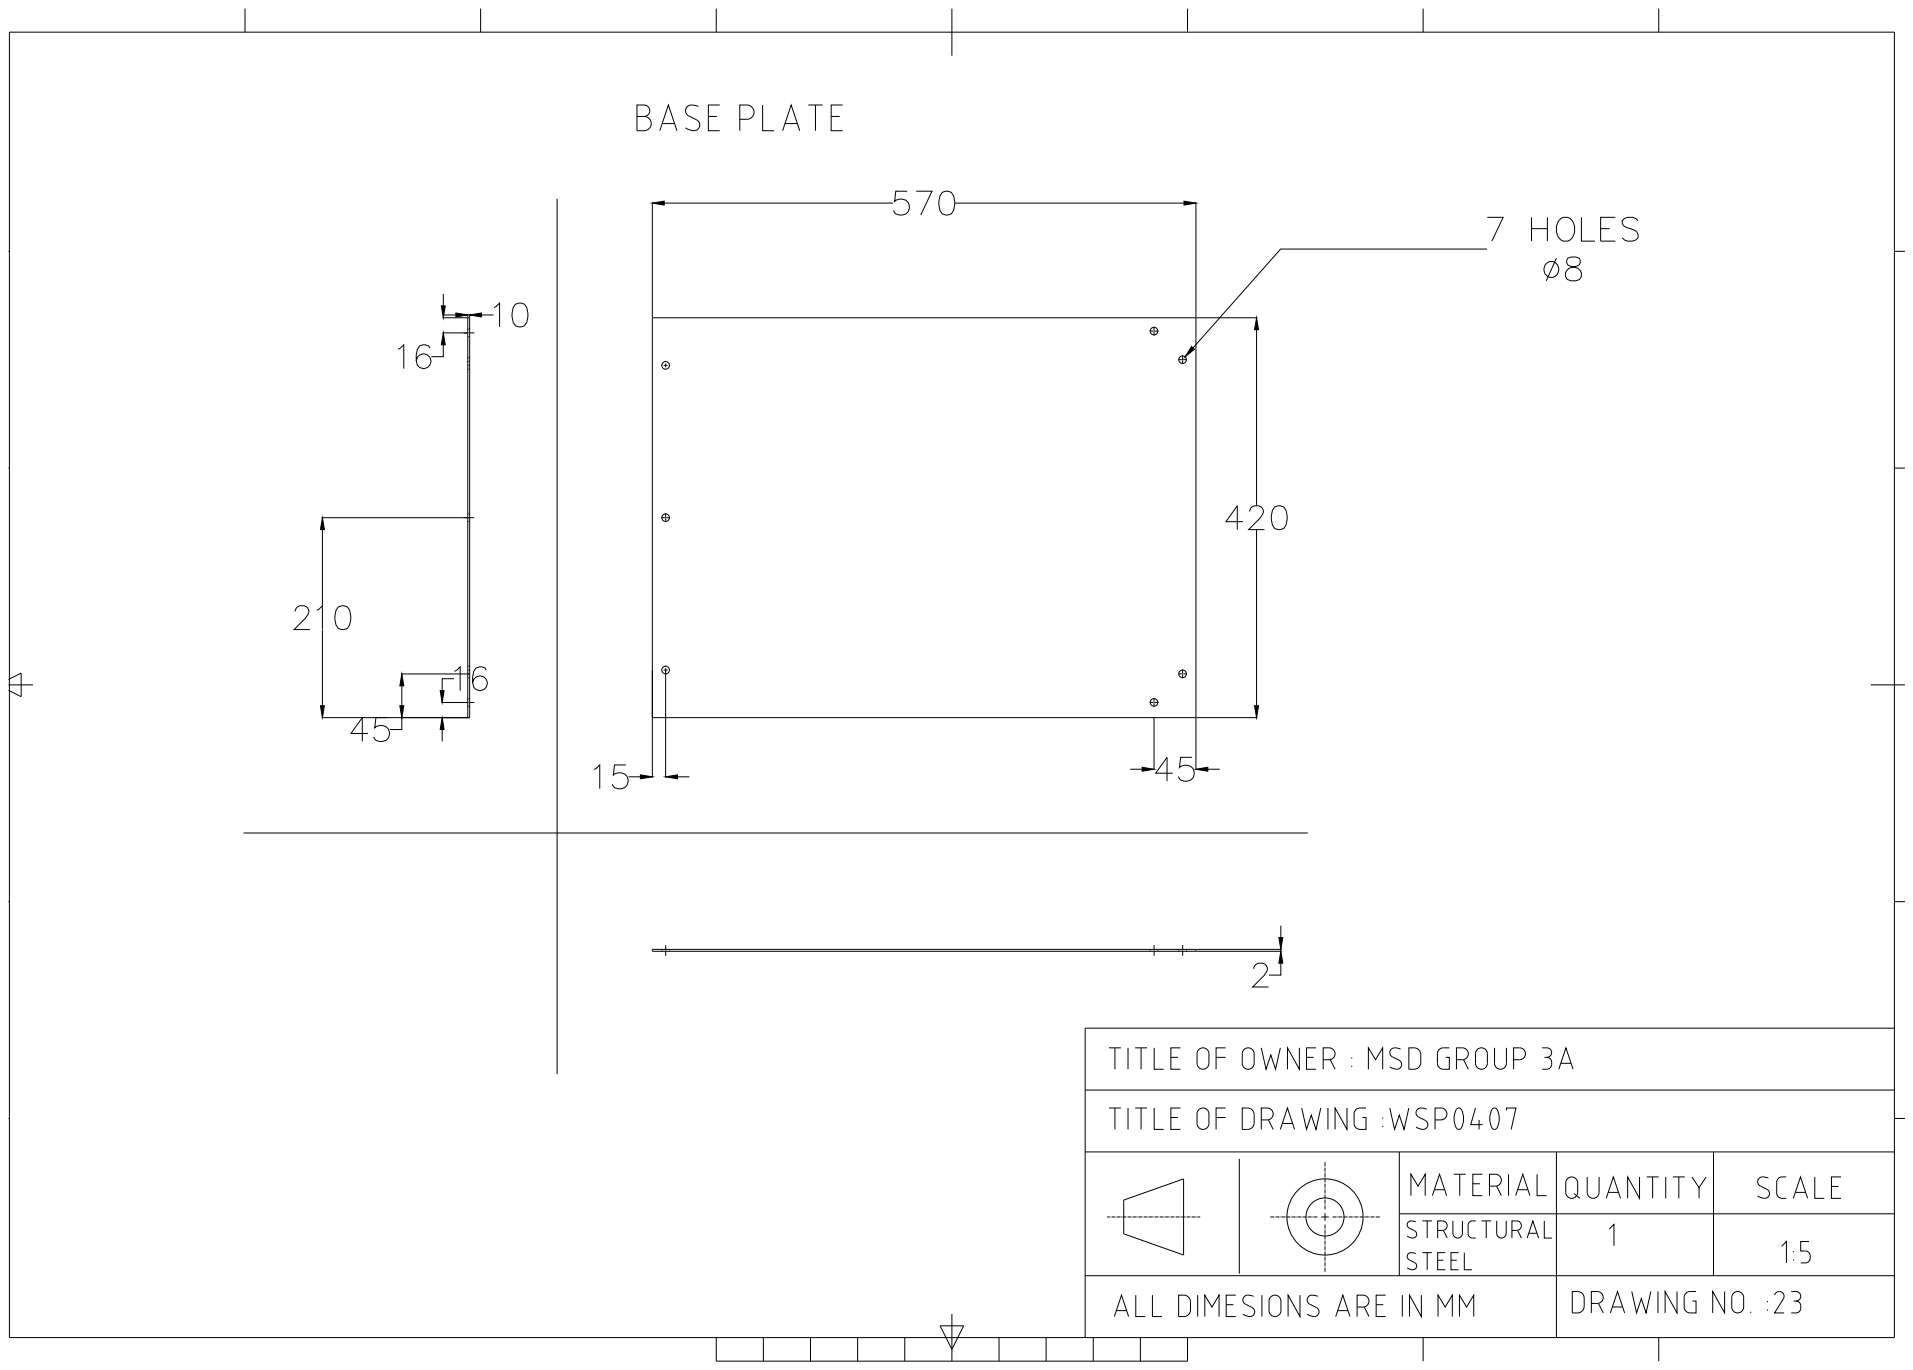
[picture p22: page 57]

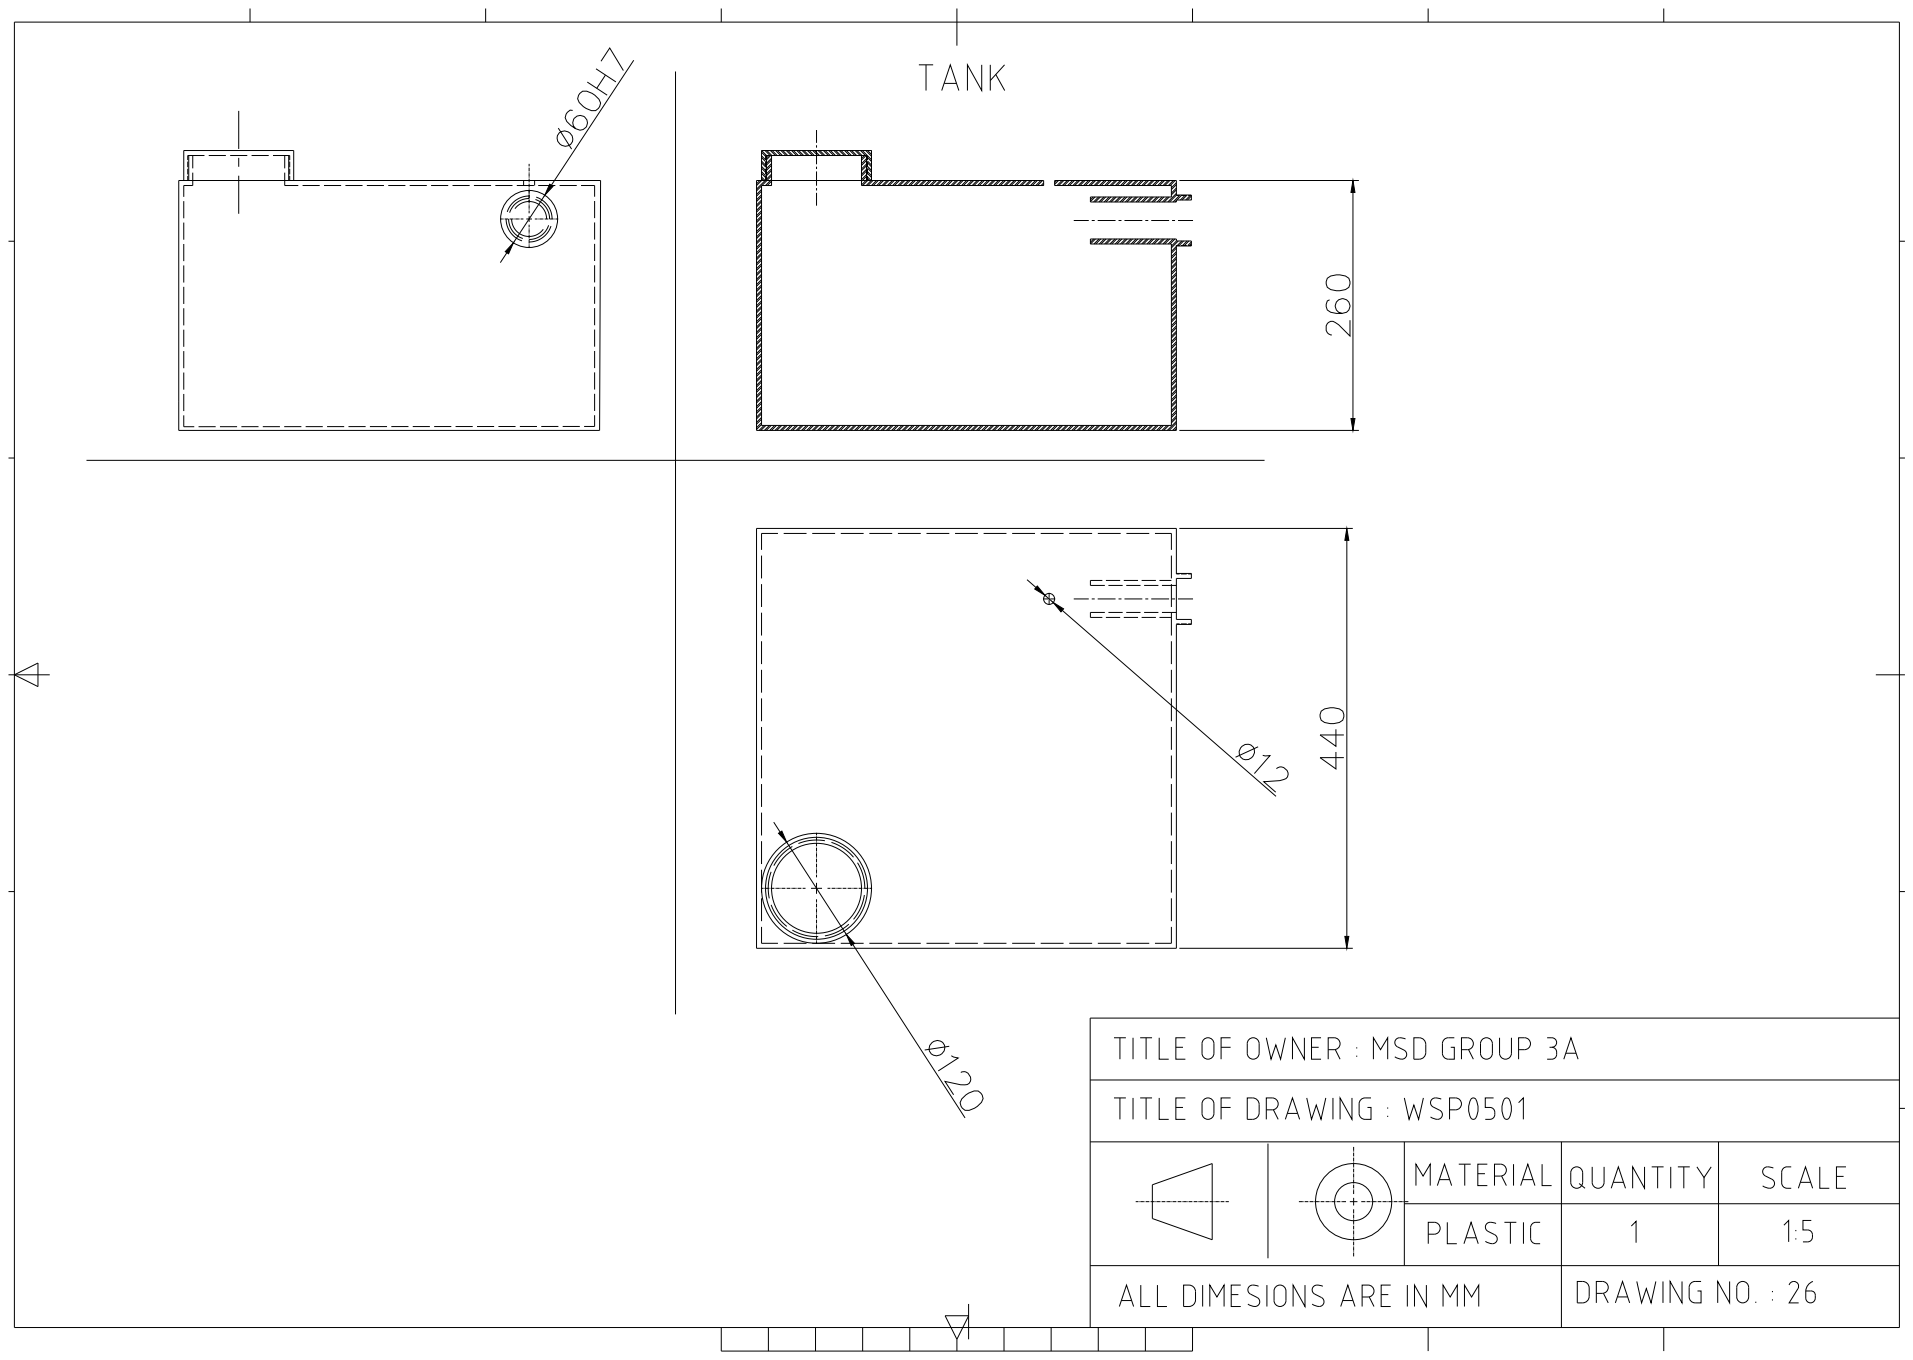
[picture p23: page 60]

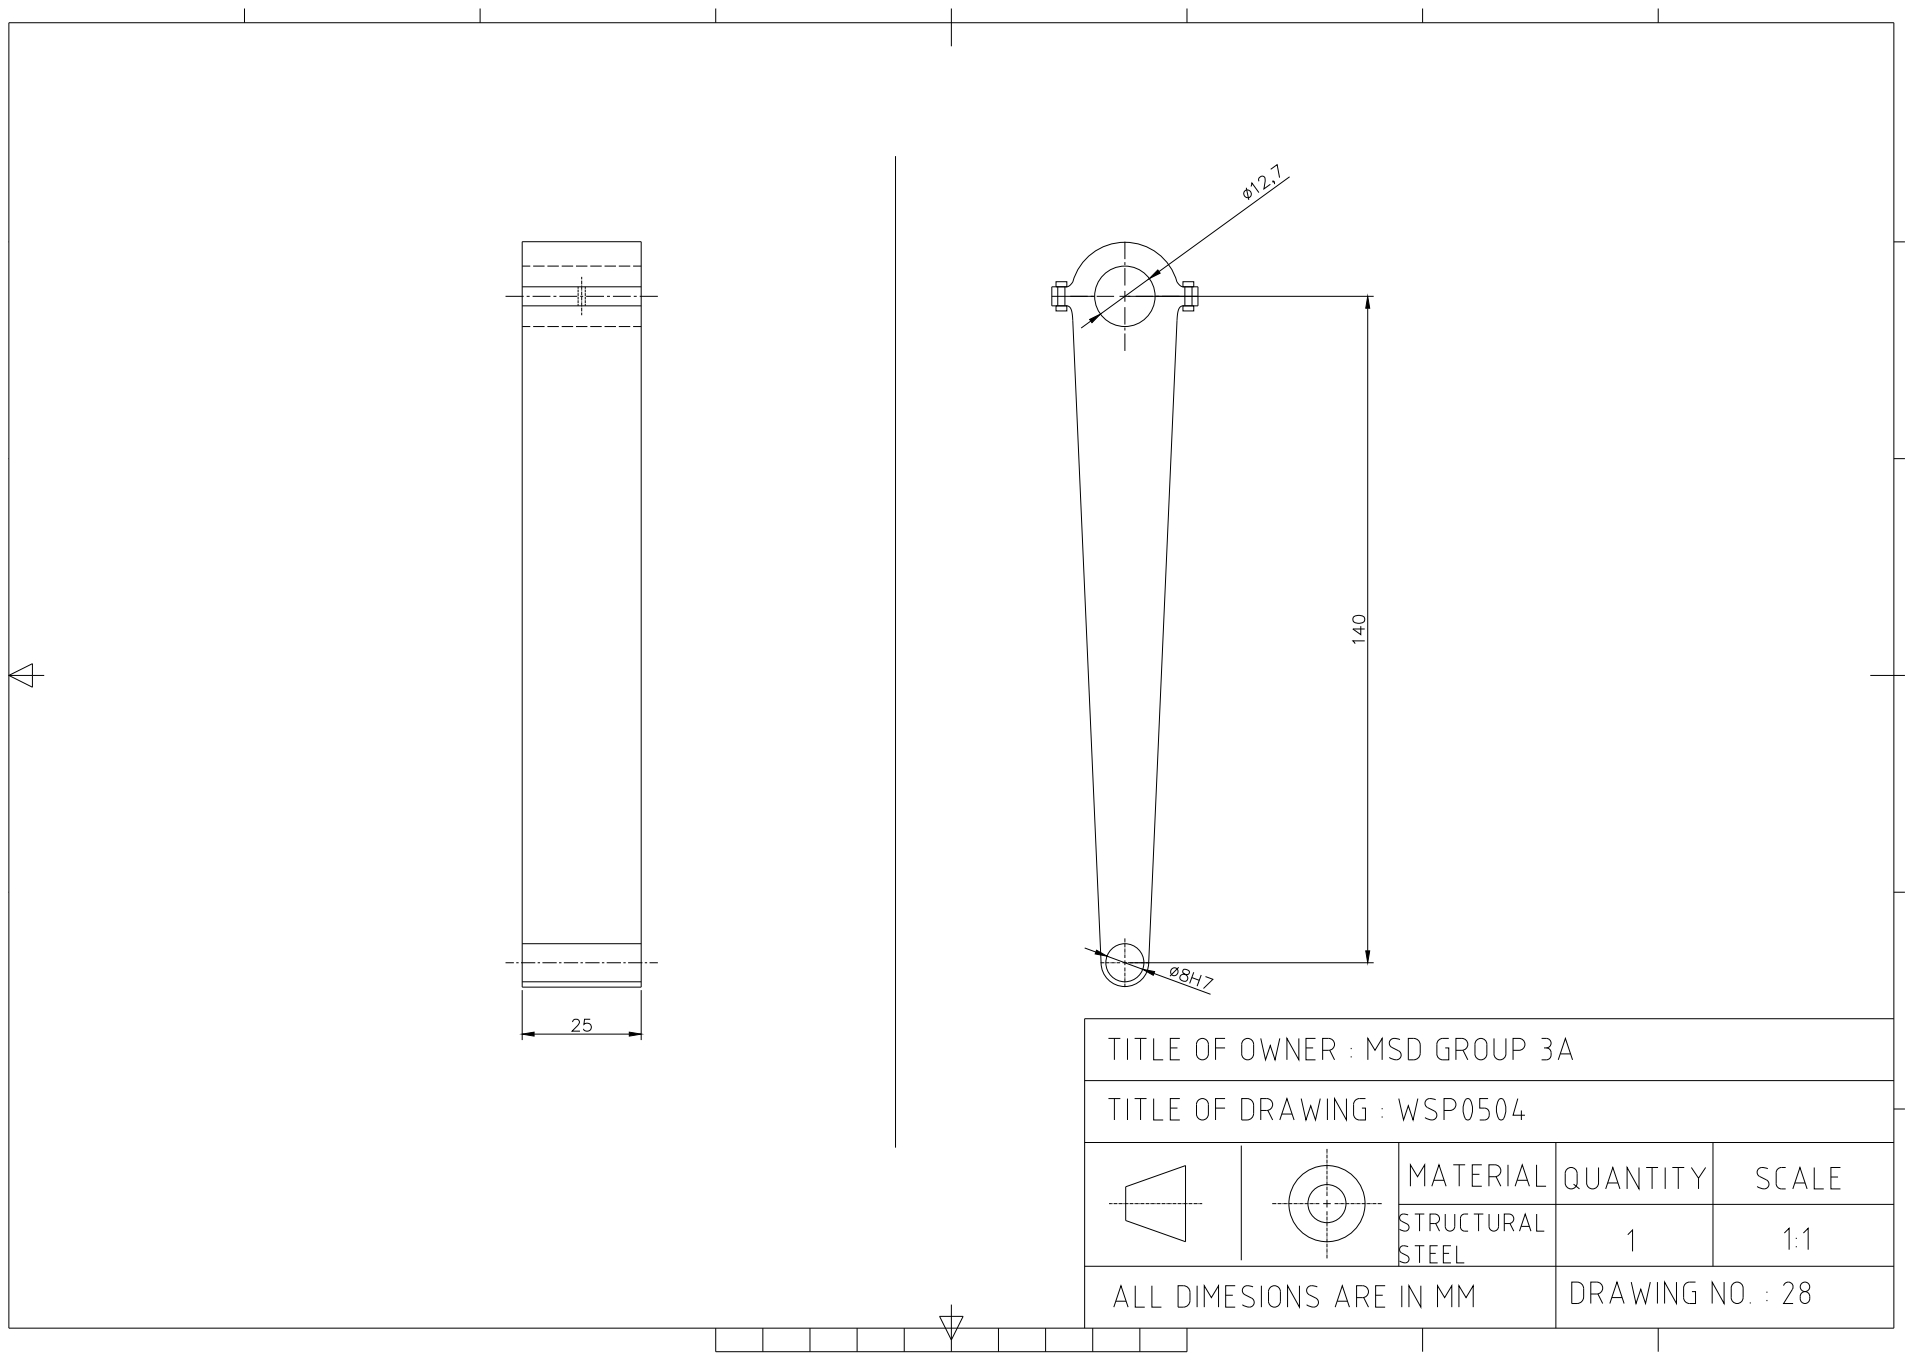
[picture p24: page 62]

12.Specifications of Machine:

a. Overall Dimensions:

Length = 1.18m

Breadth = 0.65m

Height = 1.1m

b. Power Requirement:
1. Pressure generation = 77.8Watts
2. Overcoming friction = 41.2Watts

Total Power = 119Watts

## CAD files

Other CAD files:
final assembly.dwg
